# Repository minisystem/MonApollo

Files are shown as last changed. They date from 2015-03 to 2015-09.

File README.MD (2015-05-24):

=============================
Programmable Analog Monosynth
=============================
Prototype 
-------------
Digital Board
-------------

Digital board tested and working. SPI LED driving and switch reading tested. ADC pot reading but there is some cross-talk on
potentiometer ADC channels. Allowing sufficient settling time at ADC node between reads seems to mostly remedy this
to <= 1 LSB.

------------
Analog Board
------------
DAC S&H tested and working. There is some cross-talk (<= 10mV) on adjacent CV traces, but these are currently floating. Need to test
for crosstalk again once CV targets are installed.

NOISE/LFO/S&H tested and working, except for multiplexer latch problem mentioned below. Noise gain needed to be adjusted by
changing R180 to 10K and R181 to 750K (two 1.5M 0603s stacked in parallel). Also LFO module needede R3 (on module board) changed to 270K from 1M to get proper adjustment of sine/tri symmetry.
Sine symmetry is too 'pointy' on negative transition. Perhaps D1 and D2 need to be matched for Vf?

Bugs discovered thus far:

1. 7905 power regular pin error. Power supply rendered useless by this, so board requires external supply
2. LFO DG408 demultiplexer address lines are not latched, making LFO source addressing useless. Need to add 74LC75
latch in next revision.
2. C107 S&H sample cap footprint is 0805, but there are no NP0 or film caps in this footprint. Tried X7R and there was too much
droop. Through-hole film cap is in there now and droop is better, but still about 50-60 mV per second. This could be 
related to layout and leakage across PCB traces. A second look at layout shows definite room for improvement.
3. Glide circuit: Q6 PNP matched pair BCM857BS was flipped in schematic, swapping collectors and emitters. Good grief! Can't be salavaged
by a bodge, so will have to move on to VCO mod depth control and revisit glide in next PCB revision.
4. Glide slew caps C47 and C48 are currently 0603 but need to be 0805 or 1206 or even throughhole if film caps are to be used.

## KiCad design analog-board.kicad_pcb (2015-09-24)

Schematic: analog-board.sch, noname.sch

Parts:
C1, C8, C10, C18, C19, C20, C21, C22, C93, C94, C96, C97, C98, C99, C103, C104: 1µ
C2, C9, C11, C15, C17, C23, C24, C25, C26, C27, C28, C29, C30, C31, C32, C33, C34, C35, C36, C37, C38, C39, C40, C41, C42, C43, C44, C45, C46, C85, C88, C114, C115, C117, C118, C119, C120, C121, C122, C123, C124, C125, C126, C127, C128, C129, C130, C131, C132, C133: 0.1µ
C3, C4, C5, C12, C13, C14, C16, C81, C82, C83, C84, C86, C87, C101: 10p
C6, C7: 5.6p
C47, C48: 470n
C49, C50, C51, C52, C53, C54, C55, C56, C57, C58, C59, C60, C61, C62, C63, C64, C65, C66, C67, C68, C69, C70, C71, C72, C73, C74, C75, C76, C77, C78, C79, C80: 0.01µ
C89, C91: 47μ
C90, C107: 100n
C92: 10µ
C95: 10μ
C100, C134: 22µ
C102: 4.7n
C105, C106, C108, C109: 1000µ
C110: 1.5n
C111: 100pF
C112, C113, C116: 2.2µ
C135: 47p
D1, D2, D3, D4, D5, D6, D7, D8, D9, D10: DIODE
D11, D12: LED
D13: 1N4148
EG1, EG2: EG
J1: AC IN
J2: OUT
J3: CONN_20X2
LFO1: VCO
P2: CONN_01X02
Q1, Q2, Q3, Q4, Q5, Q7, Q8, Q9, Q10, Q11, Q12, Q13, Q14, Q15, Q16, Q20: 2N3906
Q6: BCM857BS
Q17, Q18: NPN
Q19: J111
R1, R2, R3, R4, R5, R26, R27, R28, R29, R30, R79, R80, R95, R96, R97, R104, R110, R111, R112, R113, R130, R131, R132, R133, R134, R151, R183, R198: 12K
R6, R7, R8, R9, R13, R16, R17, R19, R20, R21, R87, R88, R89, R90, R98, R101, R114, R115, R118, R119, R122, R123, R124, R125, R135, R140, R188, R190: 510
R10, R11, R12, R24, R25, R91, R92, R102, R116, R117, R120, R121, R145, R174, R192: 2.2M
R14, R15, R18, R126, R127, R128, R129: 68K
R22, R23, R93, R94, R103, R146, R170, R171, R196: 18K
R31, R32, R33, R34, R38, R99, R100, R105, R136, R137, R138, R139, R152, R200: 47K
R35, R36, R37, R141, R142, R143, R144: 91K
R39, R189, R193, R206, R207: 1K
R40, R41, R42, R147, R148, R149, R150: 270K
R43, R44, R45, R46, R47, R48, R49, R50, R51, R52, R53, R54, R55, R56, R57, R58, R59, R60, R61, R62, R63, R64, R65, R66, R67, R70, R71, R72, R73, R74, R75, R77, R78, R81, R84, R153, R154, R155, R156, R157, R158, R159, R163, R164, R165, R167, R173, R175, R176, R184, R199, R202, R204: 100K
R68: 33K
R69: 1K 3300ppm/K
R76: 39K
R82, R83, R85, R86: 4.7K
R106, R107, R108, R109: 100K
R160, R205: 10K
R161: 3.3M
R162: 390K
R166, R168: 27K
R169: 680K**
R172: 47K
R177: 150K
R178: 22
R179, R185, R191, R201, R211, R213, R215: 10K
R180: 15K
R181, R203: 470K
R182: 120K
R186: 1.5K
R187, R195: 18K
R194: 20K
R197: 2.2meg
R208, R209: 220K
R210: 3.3K
R212, R214: 9.1K
R216: 270K
R217: 22K
TP1, TP2, TP3, TP4, TP5, TP6, TP7, TP8, TP9, TP10, TP11, TP12, TP13, TP14, TP15, TP16, TP17, TP18, TP19, TP20, TP21, TP22, TP23, TP24, TP25, TP26, TP27, TP28, TP29, TP30, TP31, TP32, TP33, TP34, TP35, TP36, TP37, TP38, TP39: CONN_1
TR1, TR2, TR3, TR4, TR5, TR8, TR9, TR10, TR11, TR12, TR13, TR14, TR15, TR16, TR18, TR19, TR21, TR23: 100K
TR6, TR7, TR17, TR20, TR22: 20K
U1, U2, U3, U18, U19, U29, U30, U32: LM13700
U4, U12: DG212B
U5, U8, U22, U23, U24, U25, U27, U28, U31, U33, U34, U35, U39: TL074-
U6: AD5556
U7, U15, U21, U26: TL072-
U9: AD8672
U10: ADR01
U11: DG212B; TSSOP-16
U13, U14, U16, U17, U45: DG408
U20: 74HC75
U36: 74LV573; Digikey SN74LV573APWR
U38, U41: 0 - 10V
U40: DG419
U42: 10 - 0V
U43: LM7812
U44: LM7912
U46: 7805
VCFA1: VCF_VCA
VCO1, VCO2: VCO

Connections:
+5V: C1.1 (+), C2.1, C88.1, C116.1 (+), TP35.1, U4.12 (VL), U6.28 (VDD), U11.12 (VL), U12.12 (VL), U20.5 (VCC), U36.20 (VCC), U40.5 (VCC), U46.3 (VO)
+12V: C8.1 (+), C9.1, C17.1, C18.1 (+), C21.1, C22.1, C25.1, C26.1, C27.1, C29.1, C31.1, C33.1, C35.1, C39.1, C40.1, C41.1, C43.1, C45.1, C85.1, C94.1, C97.1, C98.1, C104.1, C112.1 (+), C115.1, C118.1, C120.1, C122.1, C124.1, C126.1, C128.1, C130.1, C132.1, D9.2 (K), EG1.1 (V+), EG2.1 (V+), J3.1, J3.2, LFO1.2 (V+), R26.2, R27.2, R28.2, R29.2, R30.2, R76.2, R95.2, R96.2, R104.2, R130.2, R131.2, R133.2, R134.2, R151.2, R178.1, R184.1, R198.2, R206.1, R216.2, TP33.1, TR1.3, TR2.3, TR3.3, TR4.3, TR5.3, TR8.3, TR9.3, TR10.3, TR11.3, TR12.3, TR13.3, TR14.3, TR15.3, TR16.3, TR18.1, TR21.1, TR23.3, U1.11 (V+), U2.11 (V+), U3.11 (V+), U4.13 (V+), U5.4 (V+), U7.8 (V+), U8.4 (V+), U9.8 (V+), U10.3 (VIN), U11.13 (V+), U12.13 (V+), U13.13 (V+), U14.13 (V+), U15.8 (V+), U16.13 (V+), U17.13 (V+), U18.11 (V+), U19.11 (V+), U21.8 (V+), U22.4 (V+), U23.4 (V+), U24.4 (V+), U25.4 (V+), U26.8 (V+), U27.4 (V+), U28.4 (V+), U29.11 (V+), U30.11 (V+), U31.4 (V+), U32.11 (V+), U33.4 (V+), U34.4 (V+), U35.4 (V+), U39.4 (V+), U40.4 (V+), U43.3 (VO), U45.2 (EN), U45.13 (V+), U46.1 (VI), VCFA1.4 (V+), VCO1.2 (V+), VCO2.2 (V+)
-12V: C10.2 (-), C11.2, C19.1, C20.1, C23.1, C24.1, C28.2, C30.2, C32.2, C34.2, C36.2, C37.1, C38.1, C42.2, C44.2, C46.2, C93.1, C96.1, C99.1, C103.1, C113.2 (-), C114.1, C117.2, C119.2, C121.2, C123.2, C125.2, C127.2, C129.2, C131.2, C133.2, D10.1 (A), EG1.3 (V-), EG2.3 (V-), LFO1.3 (V-), R162.2, R207.2, R208.1, R209.1, TP34.1, TR1.1, TR2.1, TR3.1, TR4.1, TR5.1, TR8.1, TR9.1, TR10.1, TR11.1, TR12.1, TR13.1, TR14.1, TR15.1, TR16.1, TR18.3, TR19.1, TR21.3, TR23.1, U1.6 (V-), U2.6 (V-), U3.6 (V-), U4.4 (V-), U5.11 (V-), U7.4 (V-), U8.11 (V-), U9.4 (V-), U11.4 (V-), U12.4 (V-), U13.3 (V-), U14.3 (V-), U15.4 (V-), U16.3 (V-), U17.3 (V-), U18.6 (V-), U19.6 (V-), U21.4 (V-), U22.11 (V-), U23.11 (V-), U24.11 (V-), U25.11 (V-), U26.4 (V-), U27.11 (V-), U28.11 (V-), U29.6 (V-), U30.6 (V-), U31.11 (V-), U32.6 (V-), U33.11 (V-), U34.11 (V-), U35.11 (V-), U39.11 (V-), U44.3 (VO), U45.3 (V-), VCFA1.5 (V-), VCO1.3 (V-), VCO2.3 (V-)
/DAC0: J3.35, U6.6 (DB0)
/DAC1: J3.34, U6.5 (DB1)
/DAC2: J3.33, U6.4 (DB2)
/DAC3: J3.32, U6.3 (DB3)
/DAC4: J3.31, U6.2 (DB4)
/DAC5: J3.30, U6.1 (DB5)
/DAC6: J3.29, U6.27 (DB6)
/DAC7: J3.28, U6.26 (DB7)
/DAC8: J3.25, U6.25 (DB8)
/DAC9: J3.24, U6.24 (DB9)
/DAC10: J3.23, U6.23 (DB10)
/DAC11: J3.22, U6.22 (DB11)
/DAC12: J3.21, U6.21 (DB12)
/DAC13: J3.20, U6.20 (DB13)
/VREF: C15.1, TP9.1, U6.11 (R1), U10.4 (VOUT)
AMP LFO AMT CV: R146.1, U28.8, U28.9 (-)
ANALOG SW LATCH: J3.36, U36.11 (Load)
CUTOFF CV: R158.2, U28.1, U28.2 (-)
DAC MUX EN0: J3.19, U13.2 (EN)
DAC MUX EN1: J3.18, U14.2 (EN)
DAC MUX EN2: J3.17, U16.2 (EN)
DAC MUX EN3: J3.16, U17.2 (EN)
DB0: J3.8, U13.1 (A0), U14.1 (A0), U16.1 (A0), U17.1 (A0), U20.2 (D0), U36.2 (D0)
DB1: J3.9, U13.16 (A1), U14.16 (A1), U16.16 (A1), U17.16 (A1), U20.3 (D1), U36.3 (D1)
DB2: J3.10, U13.15 (A2), U14.15 (A2), U16.15 (A2), U17.15 (A2), U20.6 (D2), U36.4 (D2)
DB3: J3.11, U36.5 (D3)
DB4: J3.12, U36.6 (D4)
DB5: J3.13, U36.7 (D5)
DB6: J3.14, U36.8 (D6)
DB7: J3.15, U36.9 (D7)
EG1: EG1.6 (OUT), R154.2
EG1 ATT CV: EG1.10 (A), U33.1, U33.2 (-)
EG1 DEC CV: EG1.9 (D), U33.6 (-), U33.7
EG1 REL CV: EG1.8 (R), U33.13 (-), U33.14
EG1 SUS CV: EG1.7 (S), U33.8, U33.9 (-)
EG2: R3.1, R5.1, R111.1, U40.1 (COM)
EG2 ATT CV: EG2.10 (A), U34.1, U34.2 (-)
EG2 DEC CV: EG2.9 (D), U34.6 (-), U34.7
EG2 POL: J3.38, U40.6 (A/B)
EG2 REL CV: EG2.8 (R), U34.13 (-), U34.14
EG2 SUS CV: EG2.7 (S), U34.8, U34.9 (-)
EXT_CV_IN: R173.2, R199.2, TP38.1
FIL EG2 AMT CV: R127.1, U27.13 (-), U27.14
FIL LFO AMT CV: R128.1, U27.6 (-), U27.7
FIL OSCB AMT CV: R129.1, U27.1, U27.2 (-)
GATE: EG1.2 (GATE), EG2.2 (GATE), J3.3, TP39.1
GLIDE AMT CV: R68.2, U24.6 (-), U24.7
GND: C1.2 (-), C2.2, C8.2 (-), C9.2, C10.1 (+), C11.1, C15.2, C17.2, C18.2 (-), C19.2, C20.2, C21.2, C22.2, C23.2, C24.2, C25.2, C26.2, C27.2, C28.1, C29.2, C30.1, C31.2, C32.1, C33.2, C34.1, C35.2, C36.1, C37.2, C38.2, C39.2, C40.2, C41.2, C42.1, C43.2, C44.1, C45.2, C46.1, C47.2, C48.2, C49.2, C50.2, C51.2, C52.2, C53.2, C54.2, C55.2, C56.2, C57.2, C58.2, C59.2, C60.2, C61.2, C62.2, C63.2, C64.2, C65.2, C66.2, C67.2, C68.2, C69.2, C70.2, C71.2, C72.2, C73.2, C74.2, C75.2, C76.2, C77.2, C78.2, C79.2, C80.2, C85.2, C88.2, C89.2 (-), C90.2, C93.2, C94.2, C96.2, C97.2, C98.2, C99.2, C103.2, C104.2, C105.2 (-), C106.1 (+), C107.2, C108.2 (-), C109.1 (+), C112.2 (-), C113.1 (+), C114.2, C115.2, C116.2 (-), C117.1, C118.2, C119.1, C120.2, C121.1, C122.2, C123.1, C124.2, C125.1, C126.2, C127.1, C128.2, C129.1, C130.2, C131.1, C132.2, C133.1, D1.2 (K), D2.1 (A), D3.1 (A), D6.2 (K), D8.2 (K), D9.1 (A), D10.2 (K), D11.2 (K), D12.1 (A), EG1.4 (GND), EG2.4 (GND), J2.1, J3.39, J3.40, LFO1.1 (GND), LFO1.6 (GND), LFO1.10 (PWM), LFO1.12 (GND), Q1.2 (B), Q2.2 (B), Q3.2 (B), Q4.2 (B), Q5.2 (B), Q6.2 (B1), Q6.6 (C1), Q7.2 (B), Q8.2 (B), Q9.2 (B), Q10.2 (B), Q11.2 (B), Q12.2 (B), Q13.2 (B), Q14.2 (B), Q15.2 (B), Q16.2 (B), Q17.2 (B), Q17.3 (C), Q18.1 (E), Q20.2 (B), R6.1, R7.1, R8.1, R9.1, R13.1, R16.1, R17.1, R19.1, R20.1, R21.1, R31.1, R32.1, R33.1, R34.1, R38.1, R69.2, R87.1, R88.1, R89.1, R90.1, R98.1, R99.1, R100.1, R101.1, R105.1, R114.1, R115.1, R118.1, R119.1, R122.1, R123.1, R124.1, R125.1, R135.1, R136.1, R137.1, R138.1, R139.1, R140.1, R152.1, R160.1, R185.2, R186.2, R187.2, R188.1, R190.1, R193.2, R194.2, R200.1, R201.2, R205.2, R212.1, R214.1, R217.1, TP31.1, TP32.1, TP36.1, TP37.1, TR19.3, U4.5 (GND), U5.3 (+), U5.5 (+), U5.10 (+), U5.12 (+), U6.17 (MSB), U6.19 (GND), U7.3 (+), U7.5 (+), U8.3 (+), U8.5 (+), U8.10 (+), U8.12 (+), U9.3 (+), U9.5 (+), U10.2 (GND), U11.5 (GND), U12.5 (GND), U13.14 (GND), U14.14 (GND), U15.3 (+), U15.5 (+), U16.14 (GND), U17.14 (GND), U20.7 (D3), U20.12 (GND), U26.3 (+), U31.3 (+), U31.5 (+), U31.10 (+), U31.12 (+), U35.3 (+), U35.5 (+), U35.12 (+), U36.1 (OE), U36.10 (GND), U39.12 (+), U40.3 (GND), U40.7 (V-), U43.2 (GND), U44.1 (GND), U45.9 (S7), U45.10 (S6), U45.11 (S5), U45.14 (GND), U46.2 (GND), VCFA1.8 (GND), VCFA1.9 (GND), VCO1.1 (GND), VCO1.6 (GND), VCO1.12 (GND), VCO2.1 (GND), VCO2.6 (GND), VCO2.12 (GND)
KEYTRACK AMT CV: R126.1, U27.8, U27.9 (-)
LFO: J3.5, R1.1, R4.1, R112.1, R132.1, TP28.1, U45.8 (D)
LFO DMUX EN: J3.37, U20.4 (E23), U20.13 (E01)
LFO RATE CV: R176.2, U22.8, U22.9 (-)
LFO RESET: J3.7, LFO1.11 (SYNC)
LFO TUNE: J3.6, R215.1
NOISE: C101.2, R97.1, R181.1, R191.2, TP12.1, U39.14
NOISE MIX CV: R103.1, U23.6 (-), U23.7
unnamed: C3.1, R35.1, R40.2, U5.13 (-)
unnamed: C3.2, R40.1, R67.1, TP3.1, U5.14
unnamed: C4.1, R36.1, R41.2, U5.2 (-)
unnamed: C5.1, R37.1, R42.2, U5.9 (-)
unnamed: C6.1, U6.13 (REF), U9.1
unnamed: C6.2, U6.12 (RCOM), U9.2 (-)
unnamed: C7.2, U6.14 (IOUT), U9.6 (-)
unnamed: C12.1, R49.1, R53.2, U8.2 (-)
unnamed: C12.2, R53.1, R57.2, U8.1
unnamed: C13.1, R51.1, R54.1, U5.6 (-)
unnamed: C13.2, R54.2, R64.1, U5.7
unnamed: C14.1, R55.1, R61.2, U7.2 (-)
unnamed: C14.2, R61.1, U7.1, VCO1.10 (PWM)
unnamed: C16.1, R56.1, R62.2, U8.9 (-)
unnamed: C16.2, R62.1, U8.8, VCO2.10 (PWM)
unnamed: C47.1, U18.12, U21.3 (+)
unnamed: C48.1, U18.5, U21.5 (+)
unnamed: C81.1, R141.1, R147.2, U31.2 (-)
unnamed: C81.2, R147.1, R156.2, TP18.1, U31.1
unnamed: C82.1, R142.1, R148.2, U31.13 (-)
unnamed: C82.2, R148.1, R155.2, TP19.1, U31.14
unnamed: C83.1, R143.1, R149.2, U31.9 (-)
unnamed: C83.2, R149.1, R157.2, TP20.1, U31.8
unnamed: C84.1, R144.1, R150.2, U31.6 (-)
unnamed: C84.2, R150.1, R159.2, TP21.1, U31.7
unnamed: C86.1, R155.1, R156.1, R157.1, R158.1, R159.1, R162.1, R164.2, U35.6 (-)
unnamed: C86.2, R164.1, TP22.1, TR20.2, TR20.3, U35.7
unnamed: C87.1, R165.1, R167.2, U35.2 (-)
unnamed: C87.2, R167.1, R168.2, U35.1
unnamed: C89.1 (+), R172.1, R178.2, R179.1
unnamed: C90.1, R170.1, R171.2
unnamed: C91.1 (+), Q17.1 (E), R172.2
unnamed: C91.2 (-), Q18.2 (B), R177.2
unnamed: C92.1 (+), VCFA1.1 (IN)
unnamed: C92.2 (-), R109.2, TP30.1, U26.1
unnamed: C95.1 (+), Q18.3 (C), R177.1, R179.2, TP23.1
unnamed: C95.2 (-), R180.2
unnamed: C100.1 (+), C135.1, TP24.1, U26.5 (+), VCFA1.10 (OUT)
unnamed: C100.2 (-), R183.1
unnamed: C101.1, R180.1, R181.2, U39.13 (-)
unnamed: C102.1, LFO1.9, R210.2
unnamed: C102.2, R189.1
unnamed: C105.1 (+), C108.1 (+), D7.2 (K), D8.1 (A), P2.2, U43.1 (VI)
unnamed: C106.2 (-), C109.2 (-), D5.1 (A), D7.1 (A), U44.2 (VI)
unnamed: C107.1, Q19.1 (S), U39.5 (+)
unnamed: C110.1, R201.1, R203.2, U39.6 (-)
unnamed: C110.2, R203.1, TP27.1, U39.7, U45.12 (S4)
unnamed: C111.1, R202.2, R204.1, U35.13 (-)
unnamed: C111.2, R39.1, R204.2, U35.14
unnamed: C134.1 (+), R200.2, U32.5
unnamed: C134.2 (-), R202.1, TP26.1
unnamed: C135.2, D13.1 (A), U26.7
unnamed: D1.1 (A), D2.2 (K), R182.1, R187.1, U39.3 (+)
unnamed: D3.2 (K), R189.2, R194.1, U39.10 (+)
unnamed: D4.1 (A), Q19.3 (G), R197.2
unnamed: D4.2 (K), R215.2, TP25.1, U39.8
unnamed: D5.2 (K), D6.1 (A), J1.3
unnamed: D11.1 (A), R206.2
unnamed: D12.2 (K), R207.1
unnamed: EG2.5 (INV), U40.8 (A)
unnamed: EG2.6 (OUT), U40.2 (B)
unnamed: J1.1, P2.1
unnamed: J2.3, R39.2
unnamed: LFO1.4 (PITCH), R175.1, R176.1, TR22.1, TR22.2
unnamed: LFO1.5 (SCALE), LFO1.~ (SCALE), TR22.3
unnamed: LFO1.7, R182.2, U45.4 (S0)
unnamed: LFO1.8, U45.6 (S2)
unnamed: Q1.1 (E), R14.2
unnamed: Q1.3 (C), U1.16
unnamed: Q2.1 (E), R15.2
unnamed: Q2.3 (C), U1.1
unnamed: Q3.1 (E), R18.2
unnamed: Q3.3 (C), U2.16
unnamed: Q4.1 (E), R23.2
unnamed: Q4.3 (C), U3.1
unnamed: Q5.1 (E), R22.2
unnamed: Q5.3 (C), U3.16
unnamed: Q6.1 (E1), Q6.4 (E2), R76.1
unnamed: Q6.3 (C2), R81.2, R84.2
unnamed: Q6.5 (B2), R68.1, R69.1
unnamed: Q7.1 (E), R93.2
unnamed: Q7.3 (C), U19.16
unnamed: Q8.1 (E), R94.2
unnamed: Q8.3 (C), U19.1
unnamed: Q9.1 (E), R103.2
unnamed: Q9.3 (C), U2.1
unnamed: Q10.1 (E), R126.2
unnamed: Q10.3 (C), U29.16
unnamed: Q11.1 (E), R127.2
unnamed: Q11.3 (C), U29.1
unnamed: Q12.1 (E), R128.2
unnamed: Q12.3 (C), U30.16
unnamed: Q13.1 (E), R129.2
unnamed: Q13.3 (C), U30.1
unnamed: Q14.1 (E), R146.2
unnamed: Q14.3 (C), U32.16
unnamed: Q15.1 (E), R166.1
unnamed: Q15.3 (C), VCFA1.3 (RES)
unnamed: Q16.1 (E), R168.1
unnamed: Q16.3 (C), VCFA1.2 (AMP)
unnamed: Q19.2 (D), R191.1, R193.1, R197.1
unnamed: Q20.1 (E), R196.2
unnamed: Q20.3 (C), U32.1
unnamed: R1.2, R9.2, U3.3 (+)
unnamed: R6.2, R10.1, U1.14 (+)
unnamed: R10.2, TR1.2
unnamed: R7.2, R11.1, U1.3 (+)
unnamed: R11.2, TR2.2
unnamed: R8.2, R12.1, U2.14 (+)
unnamed: R12.2, TR3.2
unnamed: R5.2, R13.2, U3.14 (+)
unnamed: R2.2, R16.2, U1.13 (-)
unnamed: R3.2, R17.2, U1.4 (-)
unnamed: R4.2, R19.2, U2.13 (-)
unnamed: R20.2, R24.2, U3.4 (-)
unnamed: R21.2, R25.2, U3.13 (-)
unnamed: R24.1, TR4.2
unnamed: R25.1, TR5.2
unnamed: R26.1, U1.15
unnamed: R27.1, U1.2
unnamed: R28.1, U2.15
unnamed: R29.1, U3.2
unnamed: R30.1, U3.15
unnamed: R31.2, R35.2, U1.12
unnamed: R32.2, R36.2, U1.5
unnamed: R33.2, R37.2, U2.12
unnamed: R47.2, U4.7
unnamed: R48.2, U4.10
unnamed: R50.1, R55.2, TP6.1, U7.7
unnamed: R52.1, R56.2, TP7.1, U8.7
unnamed: R58.2, U4.2
unnamed: R60.2, U4.15
unnamed: R70.1, R71.1, R72.1, R77.2, U15.2 (-)
unnamed: R70.2, U11.10
unnamed: R71.2, U11.15
unnamed: R72.2, U11.2
unnamed: R73.1, R74.1, R75.1, R78.2, U15.6 (-)
unnamed: R73.2, U12.15
unnamed: R74.2, U12.2
unnamed: R75.2, U12.7
unnamed: R77.1, R79.1, TP10.1, U15.1
unnamed: R78.1, R80.1, TP11.1, U15.7
unnamed: R79.2, R87.2, U19.14 (+)
unnamed: R80.2, R88.2, U19.3 (+)
unnamed: R81.1, U18.16
unnamed: R82.2, U18.14 (+)
unnamed: R83.2, U18.13 (-)
unnamed: R84.1, U18.1
unnamed: R85.2, U18.3 (+)
unnamed: R86.2, U18.4 (-)
unnamed: R89.2, R91.2, U19.13 (-)
unnamed: R90.2, R92.2, U19.4 (-)
unnamed: R91.1, TR8.2
unnamed: R92.1, TR9.2
unnamed: R95.1, U19.15
unnamed: R96.1, U19.2
unnamed: R97.2, R98.2, U2.3 (+)
unnamed: R100.2, R108.1, TP16.1, U19.5
unnamed: R101.2, R102.2, U2.4 (-)
unnamed: R102.1, TR10.2
unnamed: R104.1, U2.2
unnamed: R105.2, R107.1, TP15.1, U2.5
unnamed: R99.2, R106.1, TP17.1, U19.12
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

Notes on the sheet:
DG212 POWER CONNECTIONS
LFO SPEED INIT
Adjust R(Iabc) for unity gain
CV MIX OFFSET NULL
SELECTED
NP0 or FILM
LFO CLOCK
S&H OUT
S&H
PULSE
SAW
SINE
TRI
LFO + NOISE + S&H
SCALE TRIM
GLIDE
VCF CTRL offset
(+4V to -6V)
**may need to lower to 510K or 560K for 12V PWR
VCF CTRL input modified from Juno 106 VCF input for 0-10V response
ENVELOPE GENERATORS
ANALOG SWITCH LATCH
DAC BUS
S&H DECOUPLING
VDAC MULTIPLEXING
CV SAMPLE & HOLDS
DAC and DAC 10V reference
12V AC from wall adapter
POWER SUPPLY
NOISE + S&H from YUSYNTH LFO module is VCO SIP with 100nF integrator cap and 1nF FET reset cap
ADAPTED FROM SCI PROPHET 5 GLIDE CIRCUIT
*** PULSE FALLING EDGE THEN RISING EDGE SEE AD5556 DATASHEET
***
single turn
SPARE
A GND
D GND
SWITCH JUMPER
OP AMP and SWITCH DECOUPLING
EXT CV IN

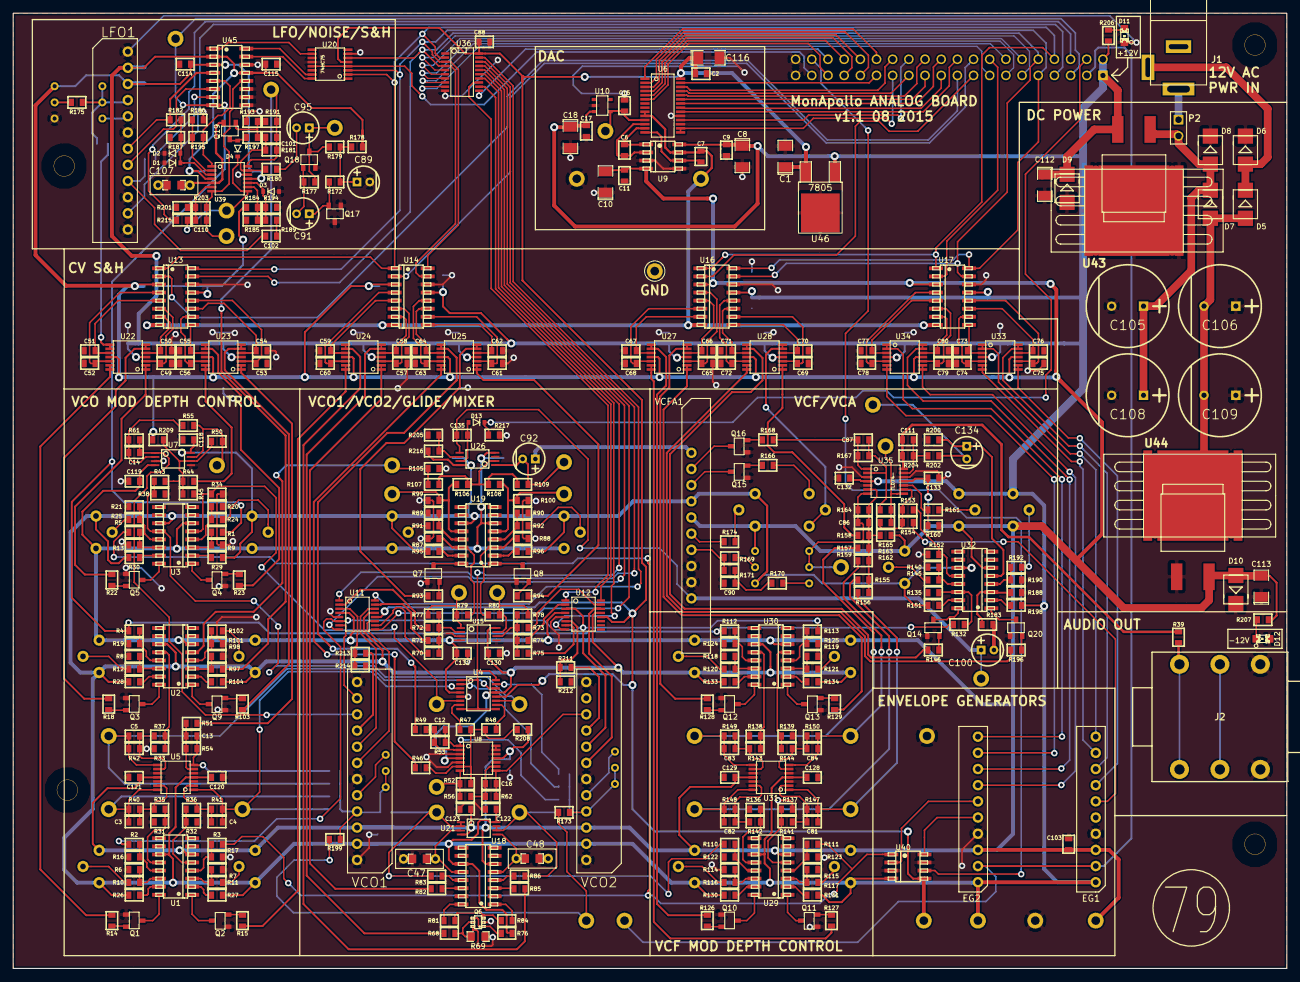
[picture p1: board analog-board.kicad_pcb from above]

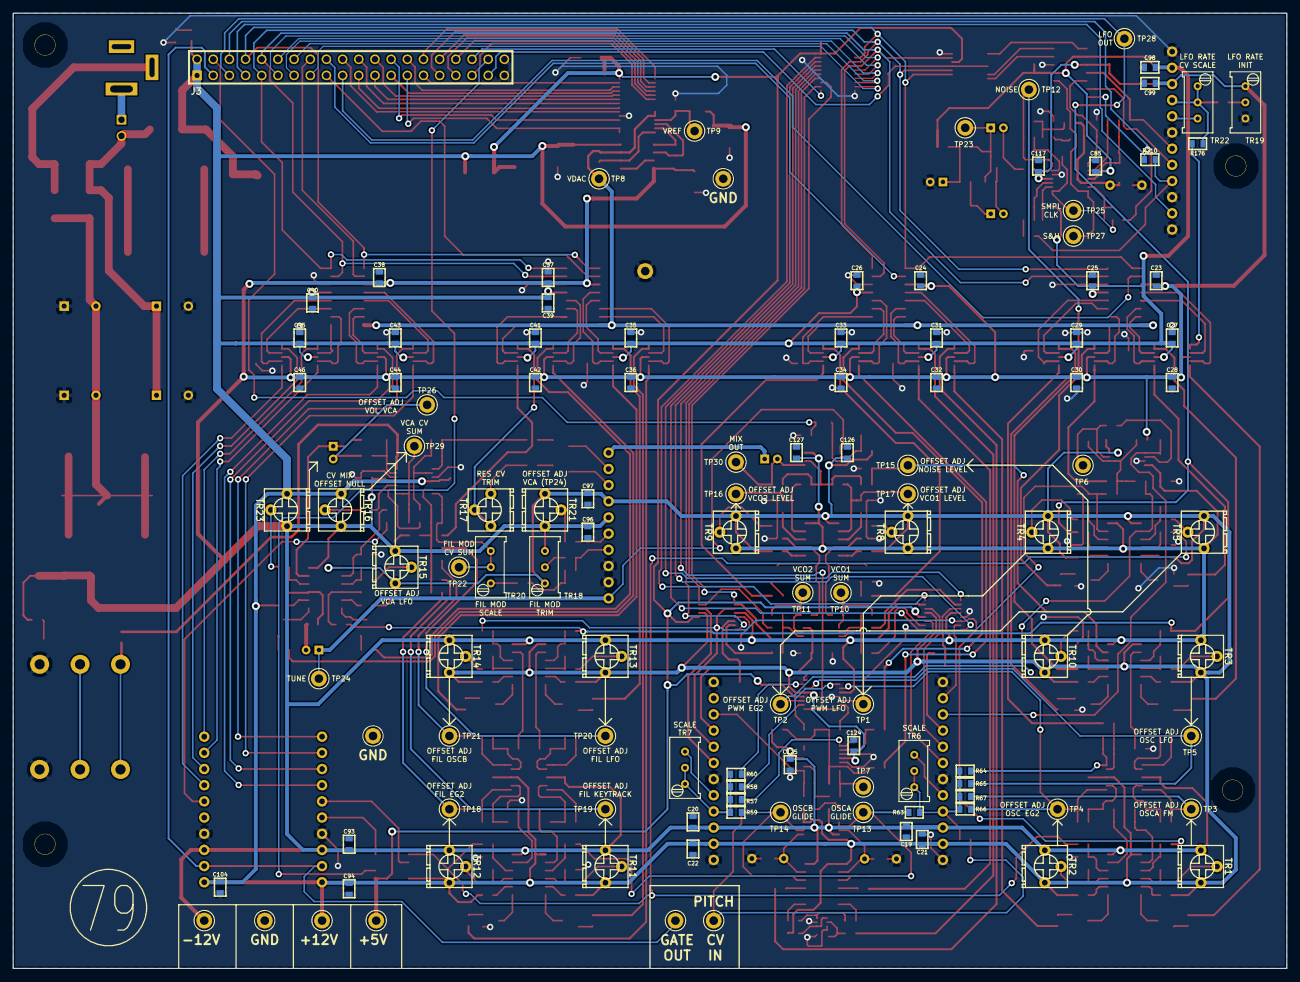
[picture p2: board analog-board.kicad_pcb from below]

Board: 2 copper layers, 200.0 x 150.0 mm, 506 parts (115 on the bottom side), 352 nets.

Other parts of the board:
HOLE-0.125-INCH, HOLE-0.125-INCH#2, HOLE-0.125-INCH#3, HOLE-0.125-INCH#4: VAL**; HOLE-0.125-INCH

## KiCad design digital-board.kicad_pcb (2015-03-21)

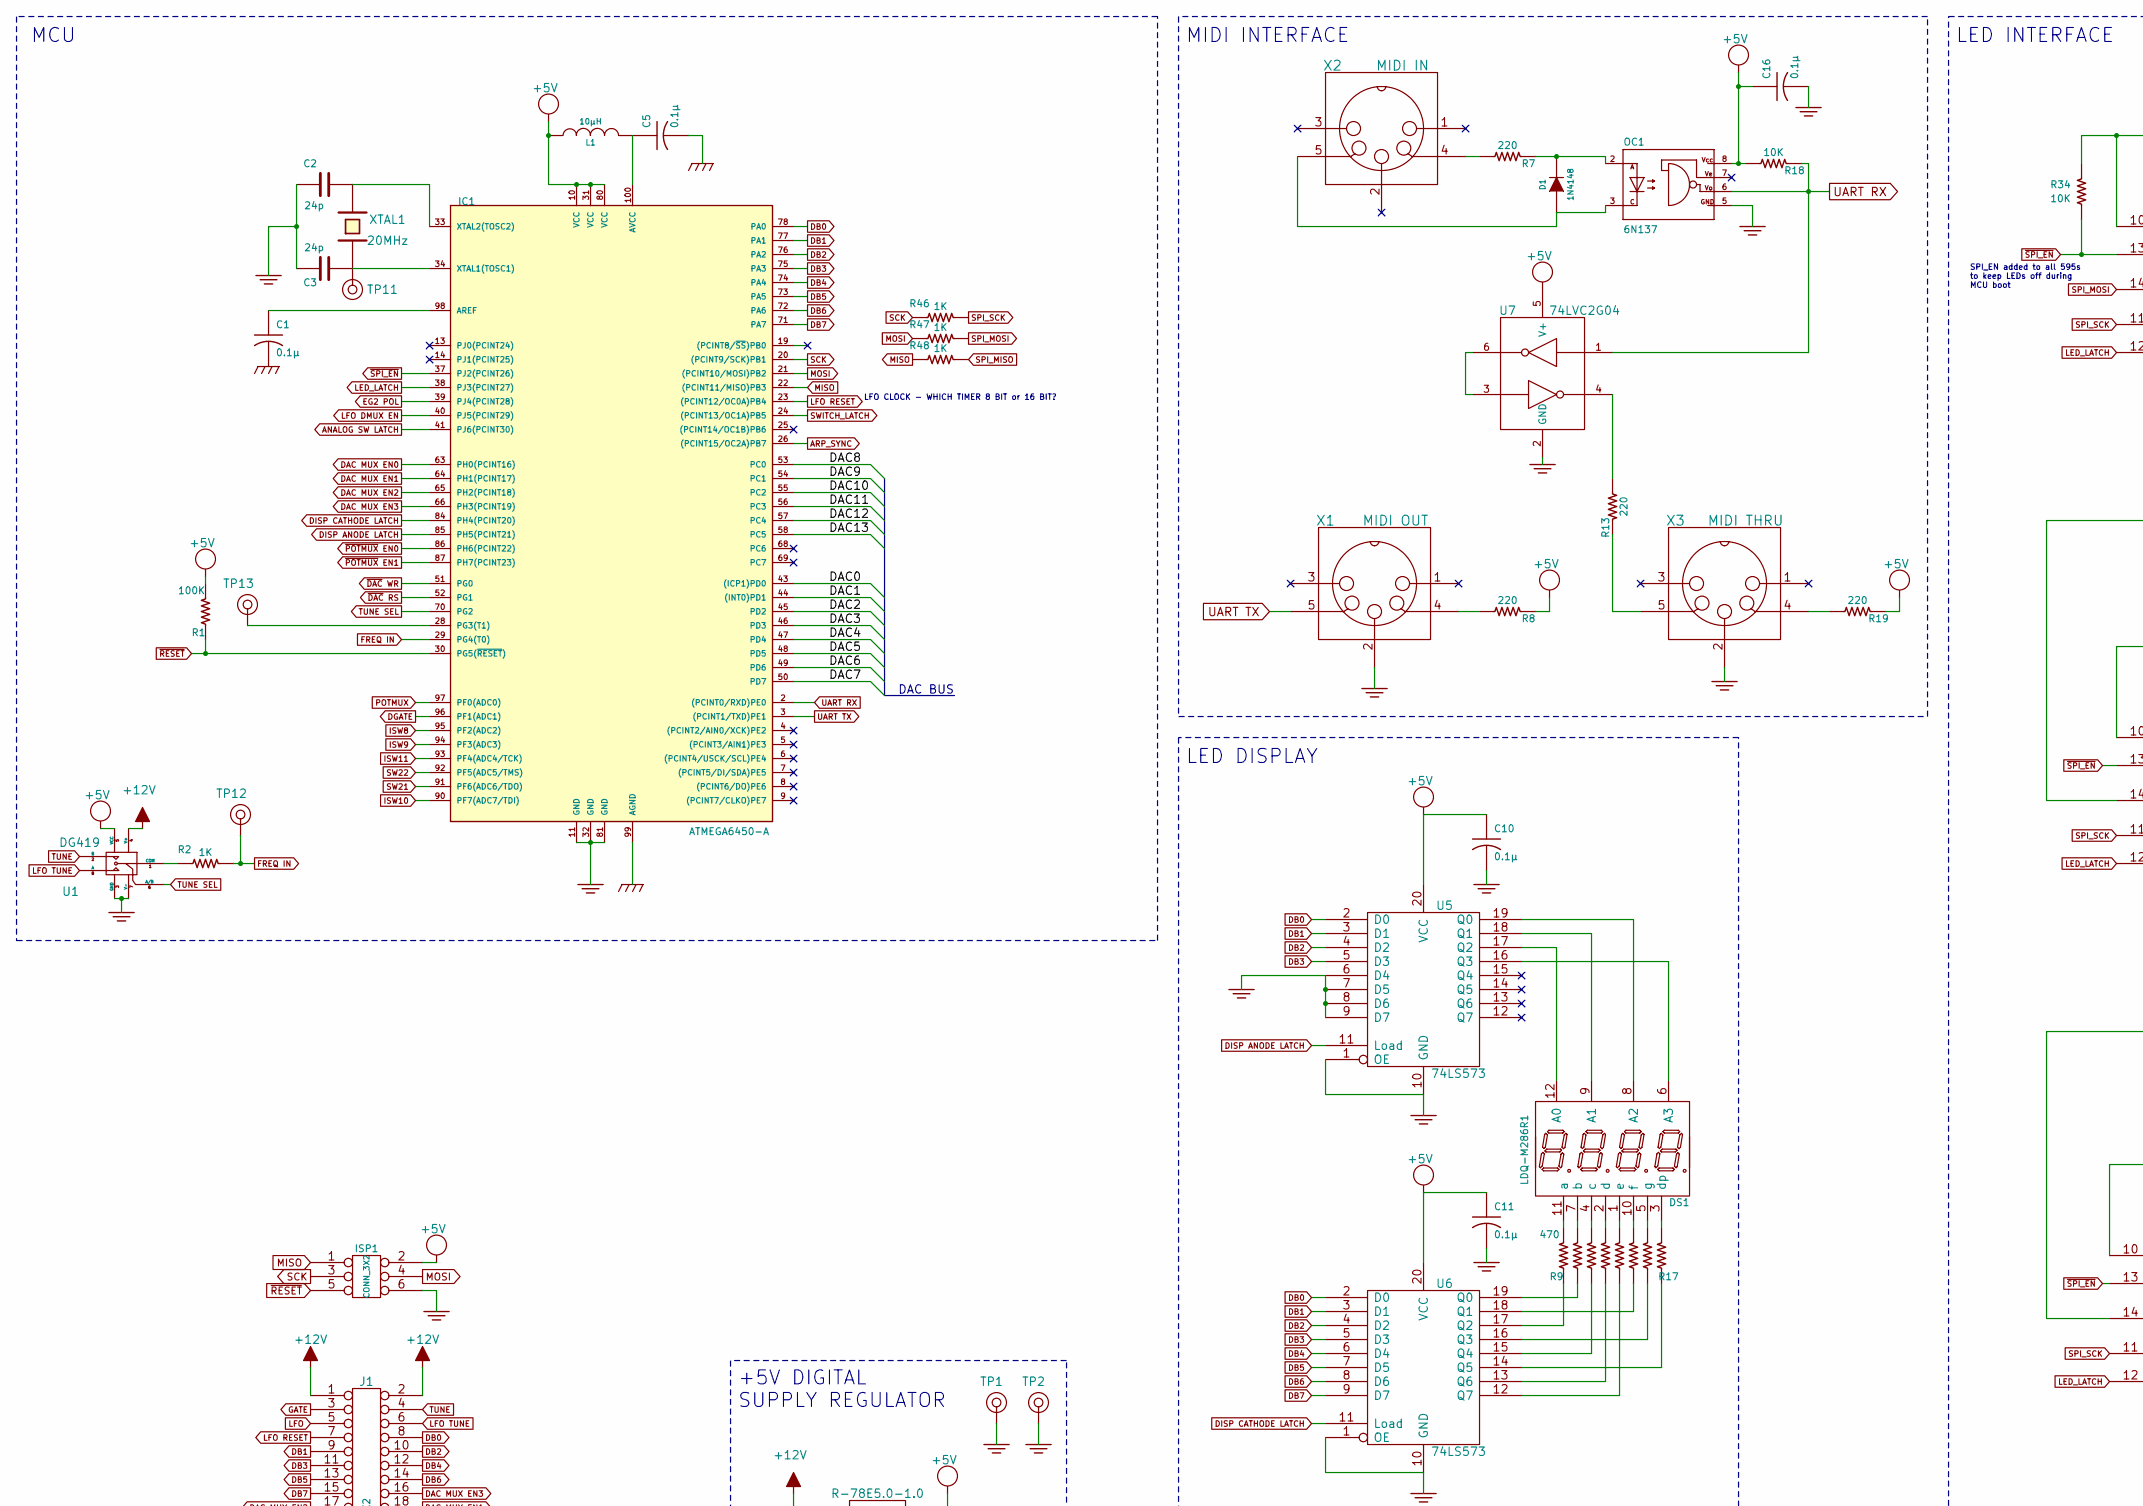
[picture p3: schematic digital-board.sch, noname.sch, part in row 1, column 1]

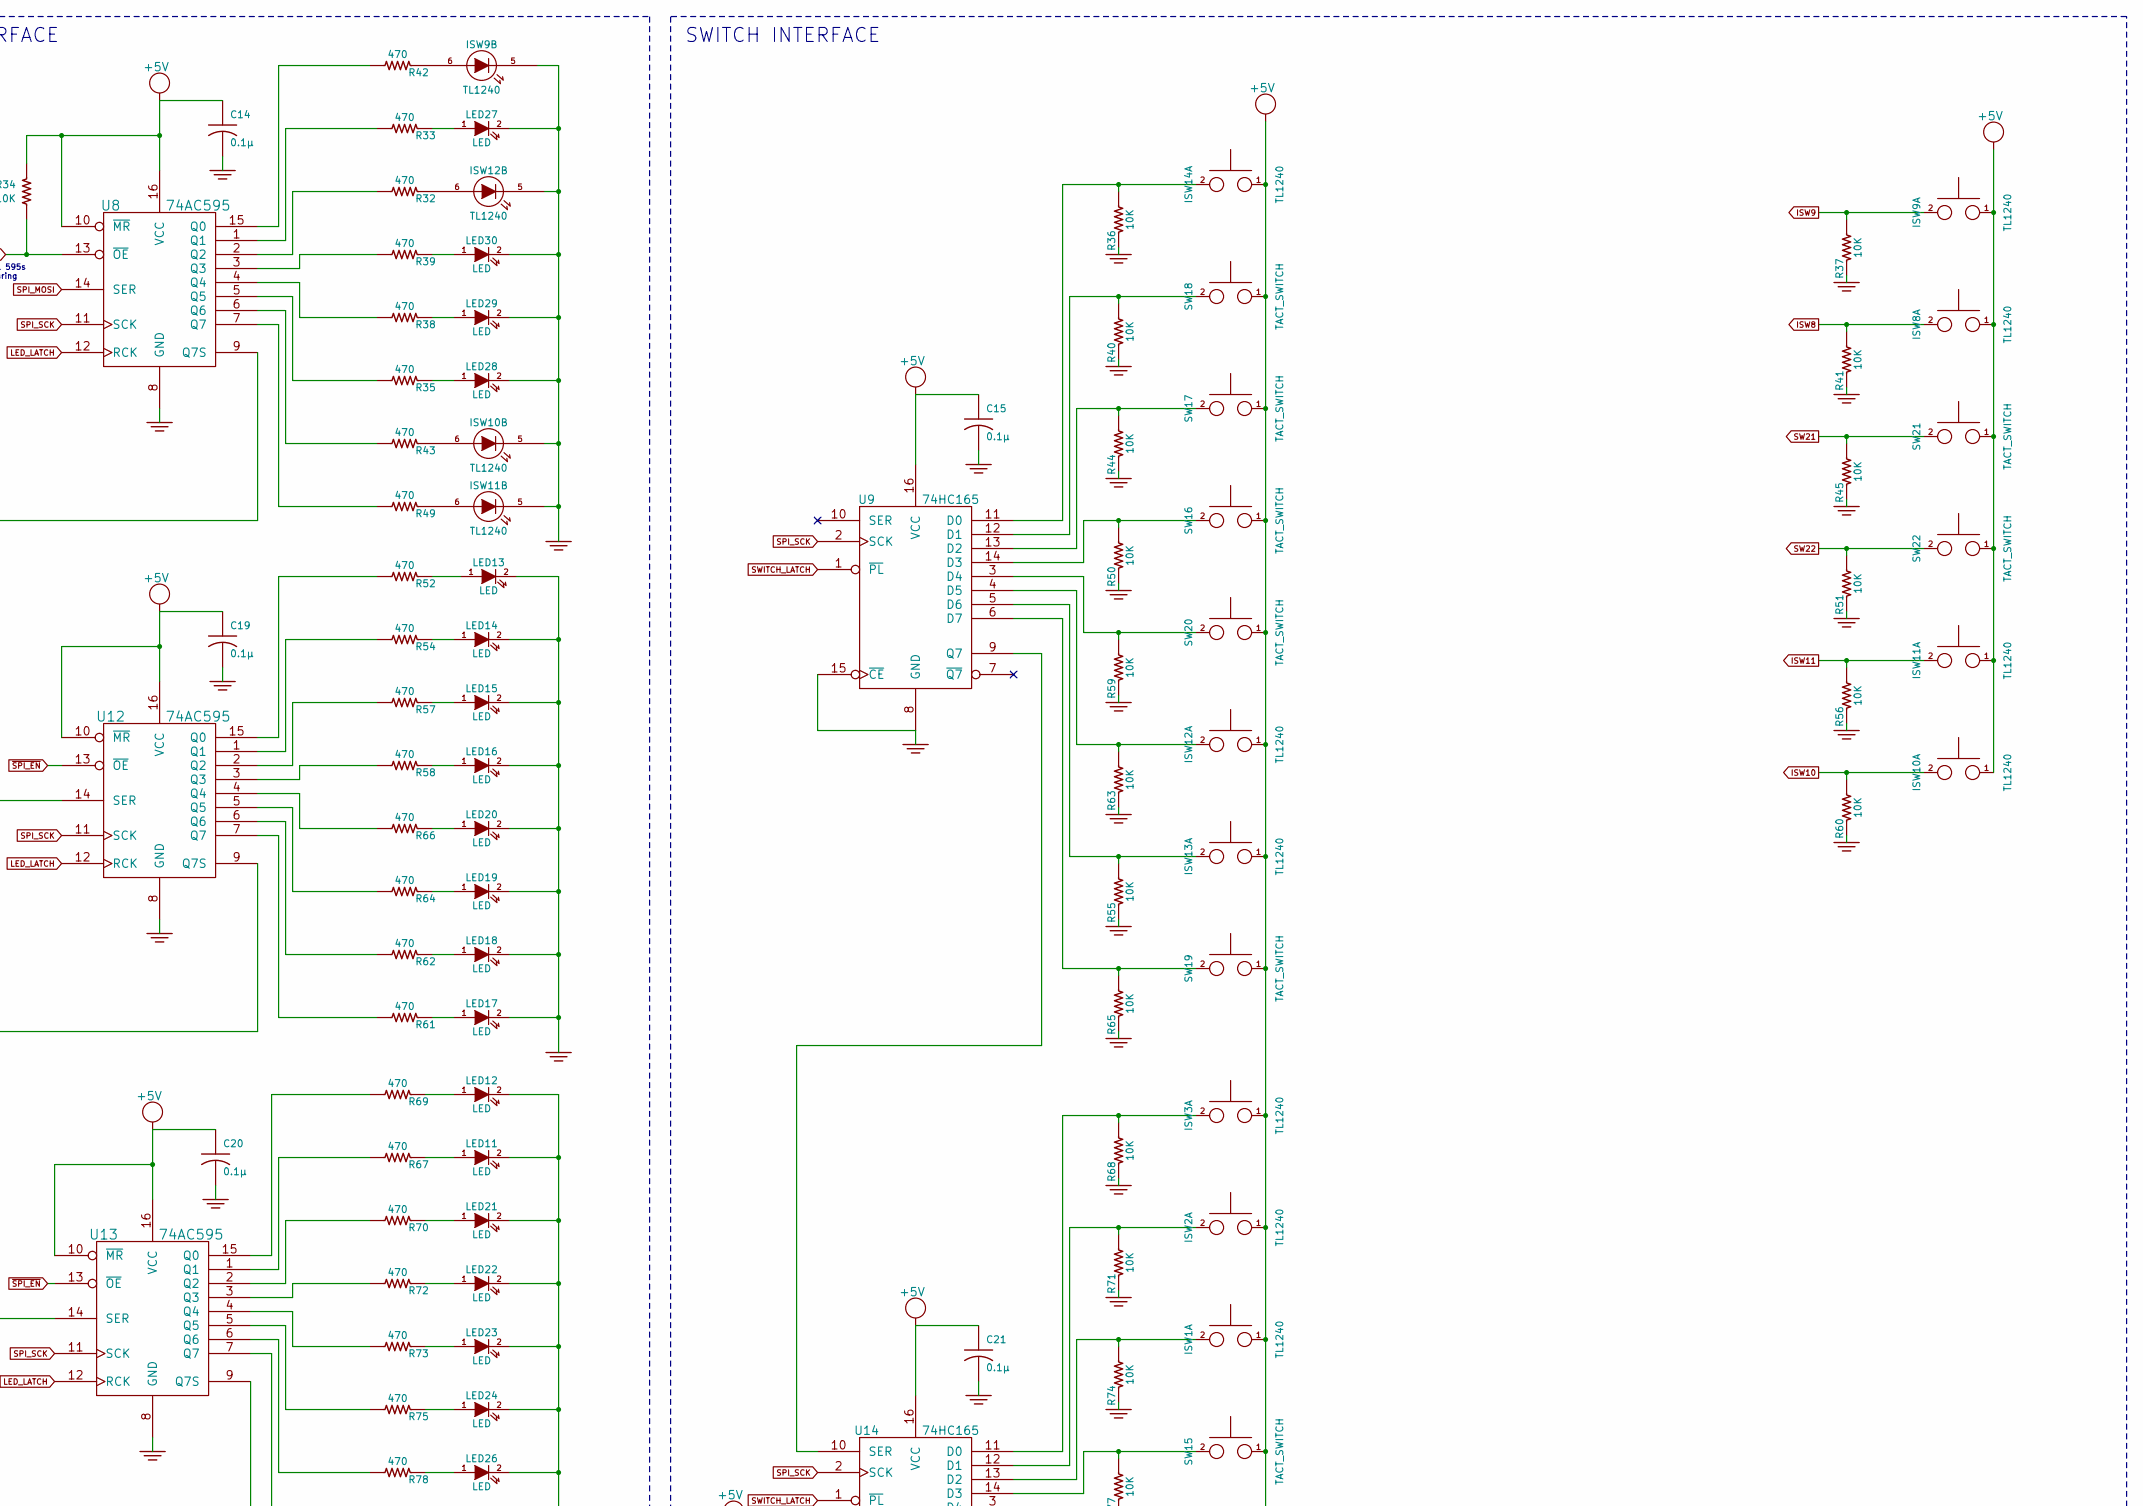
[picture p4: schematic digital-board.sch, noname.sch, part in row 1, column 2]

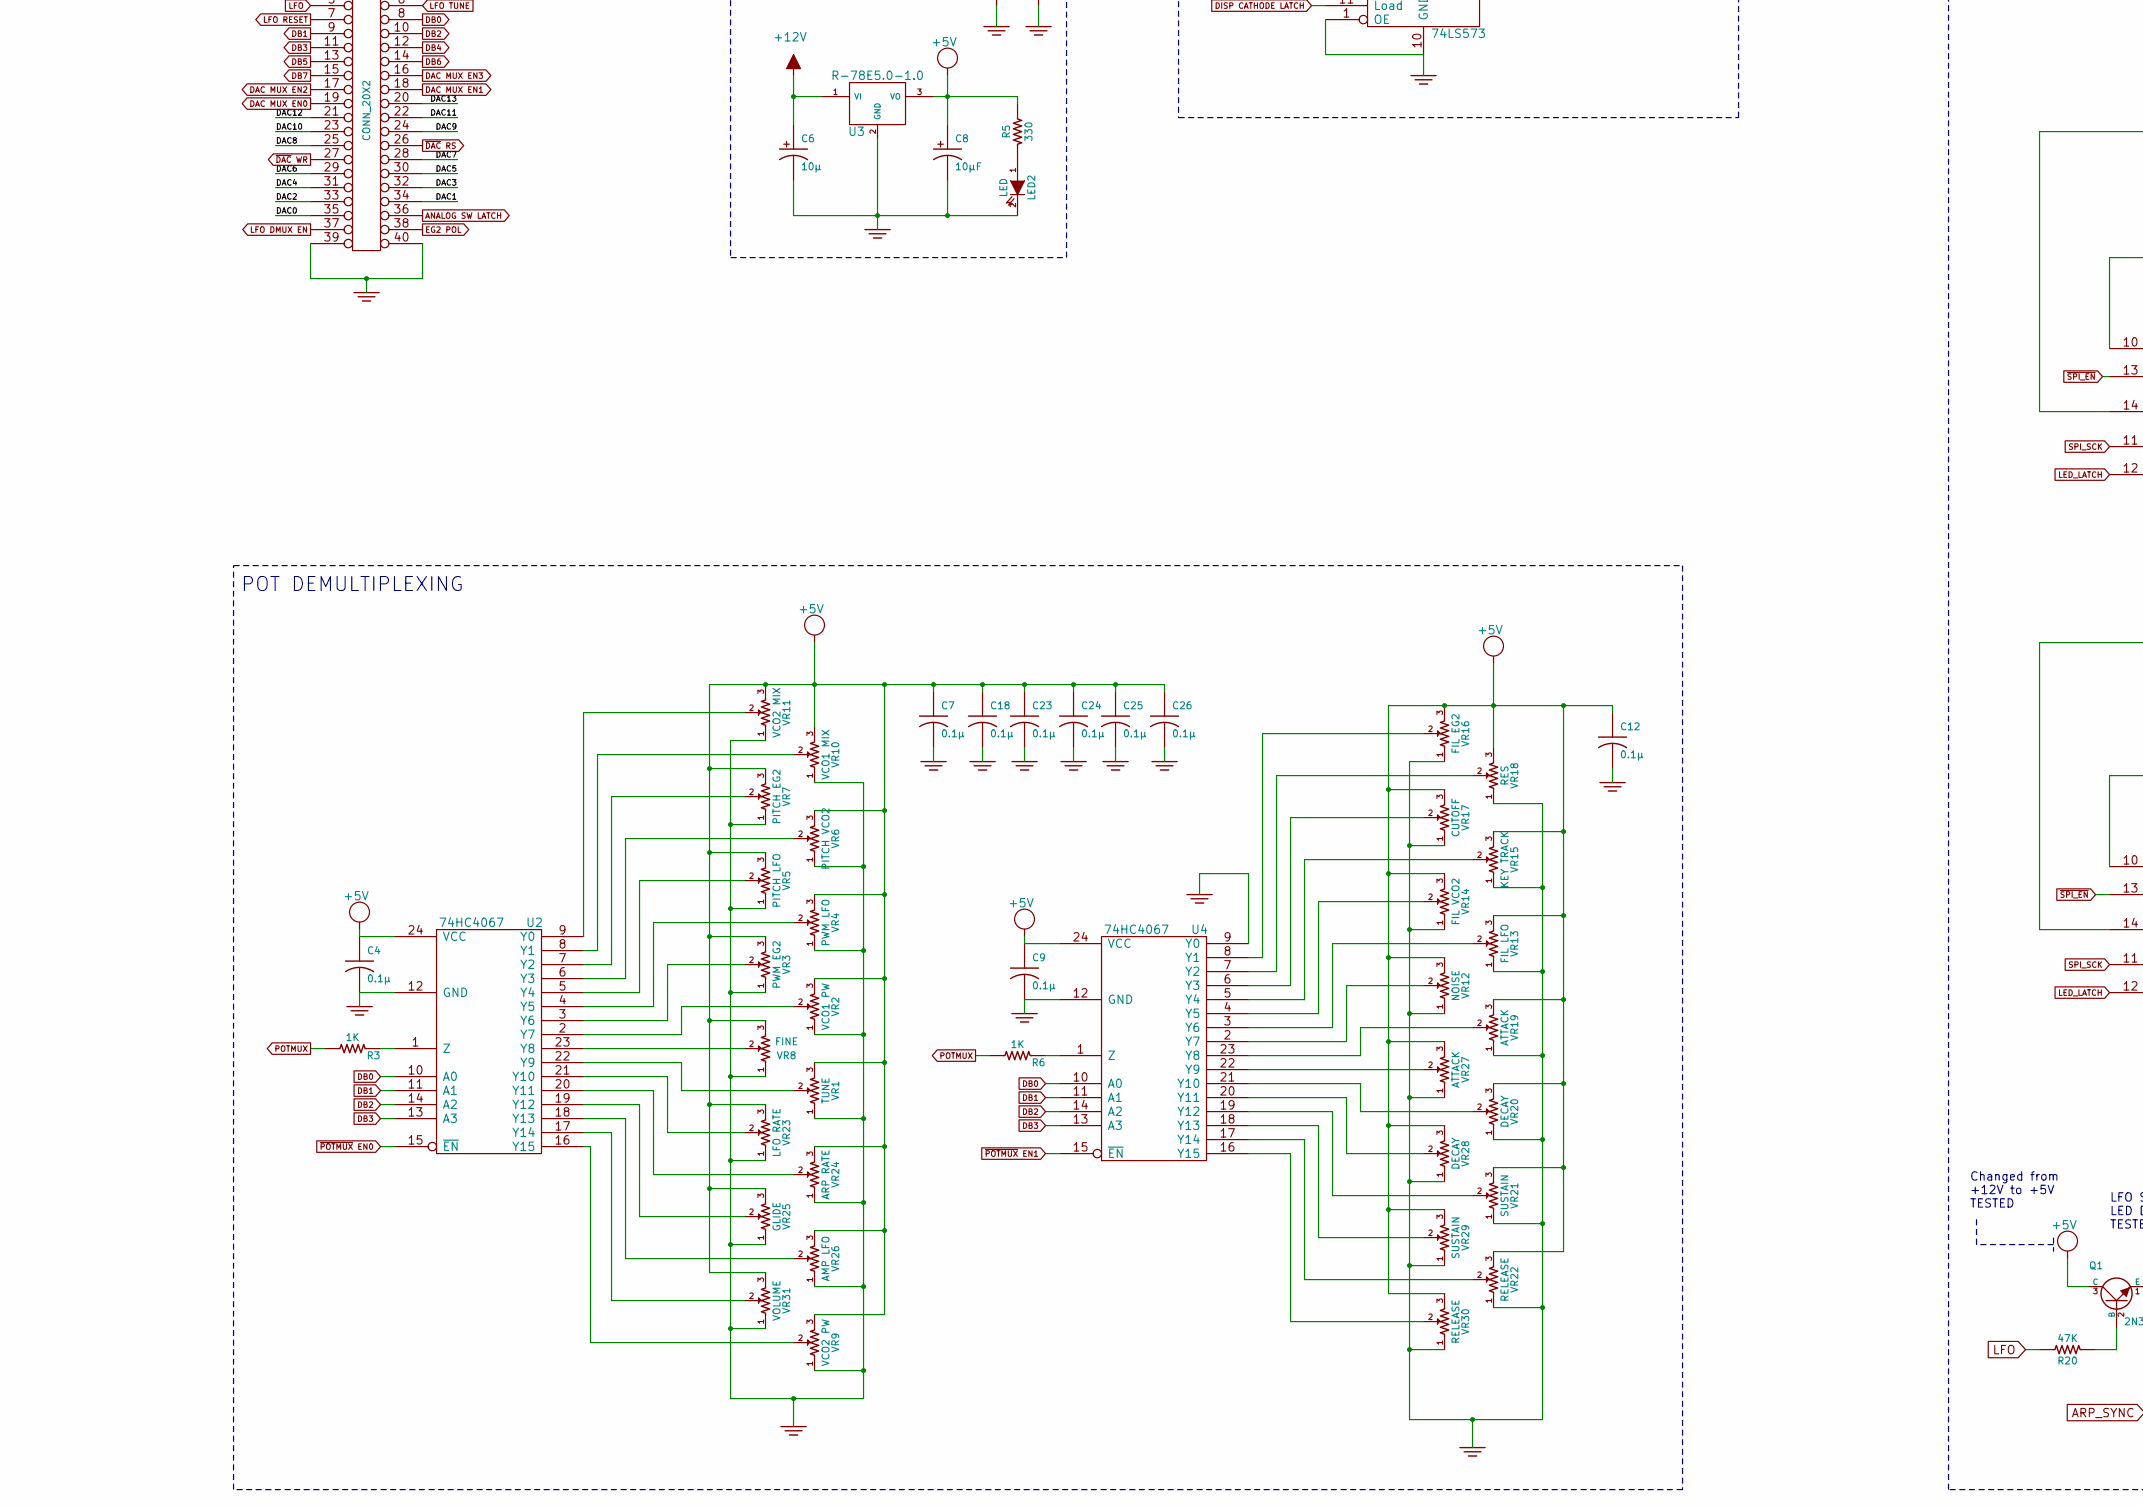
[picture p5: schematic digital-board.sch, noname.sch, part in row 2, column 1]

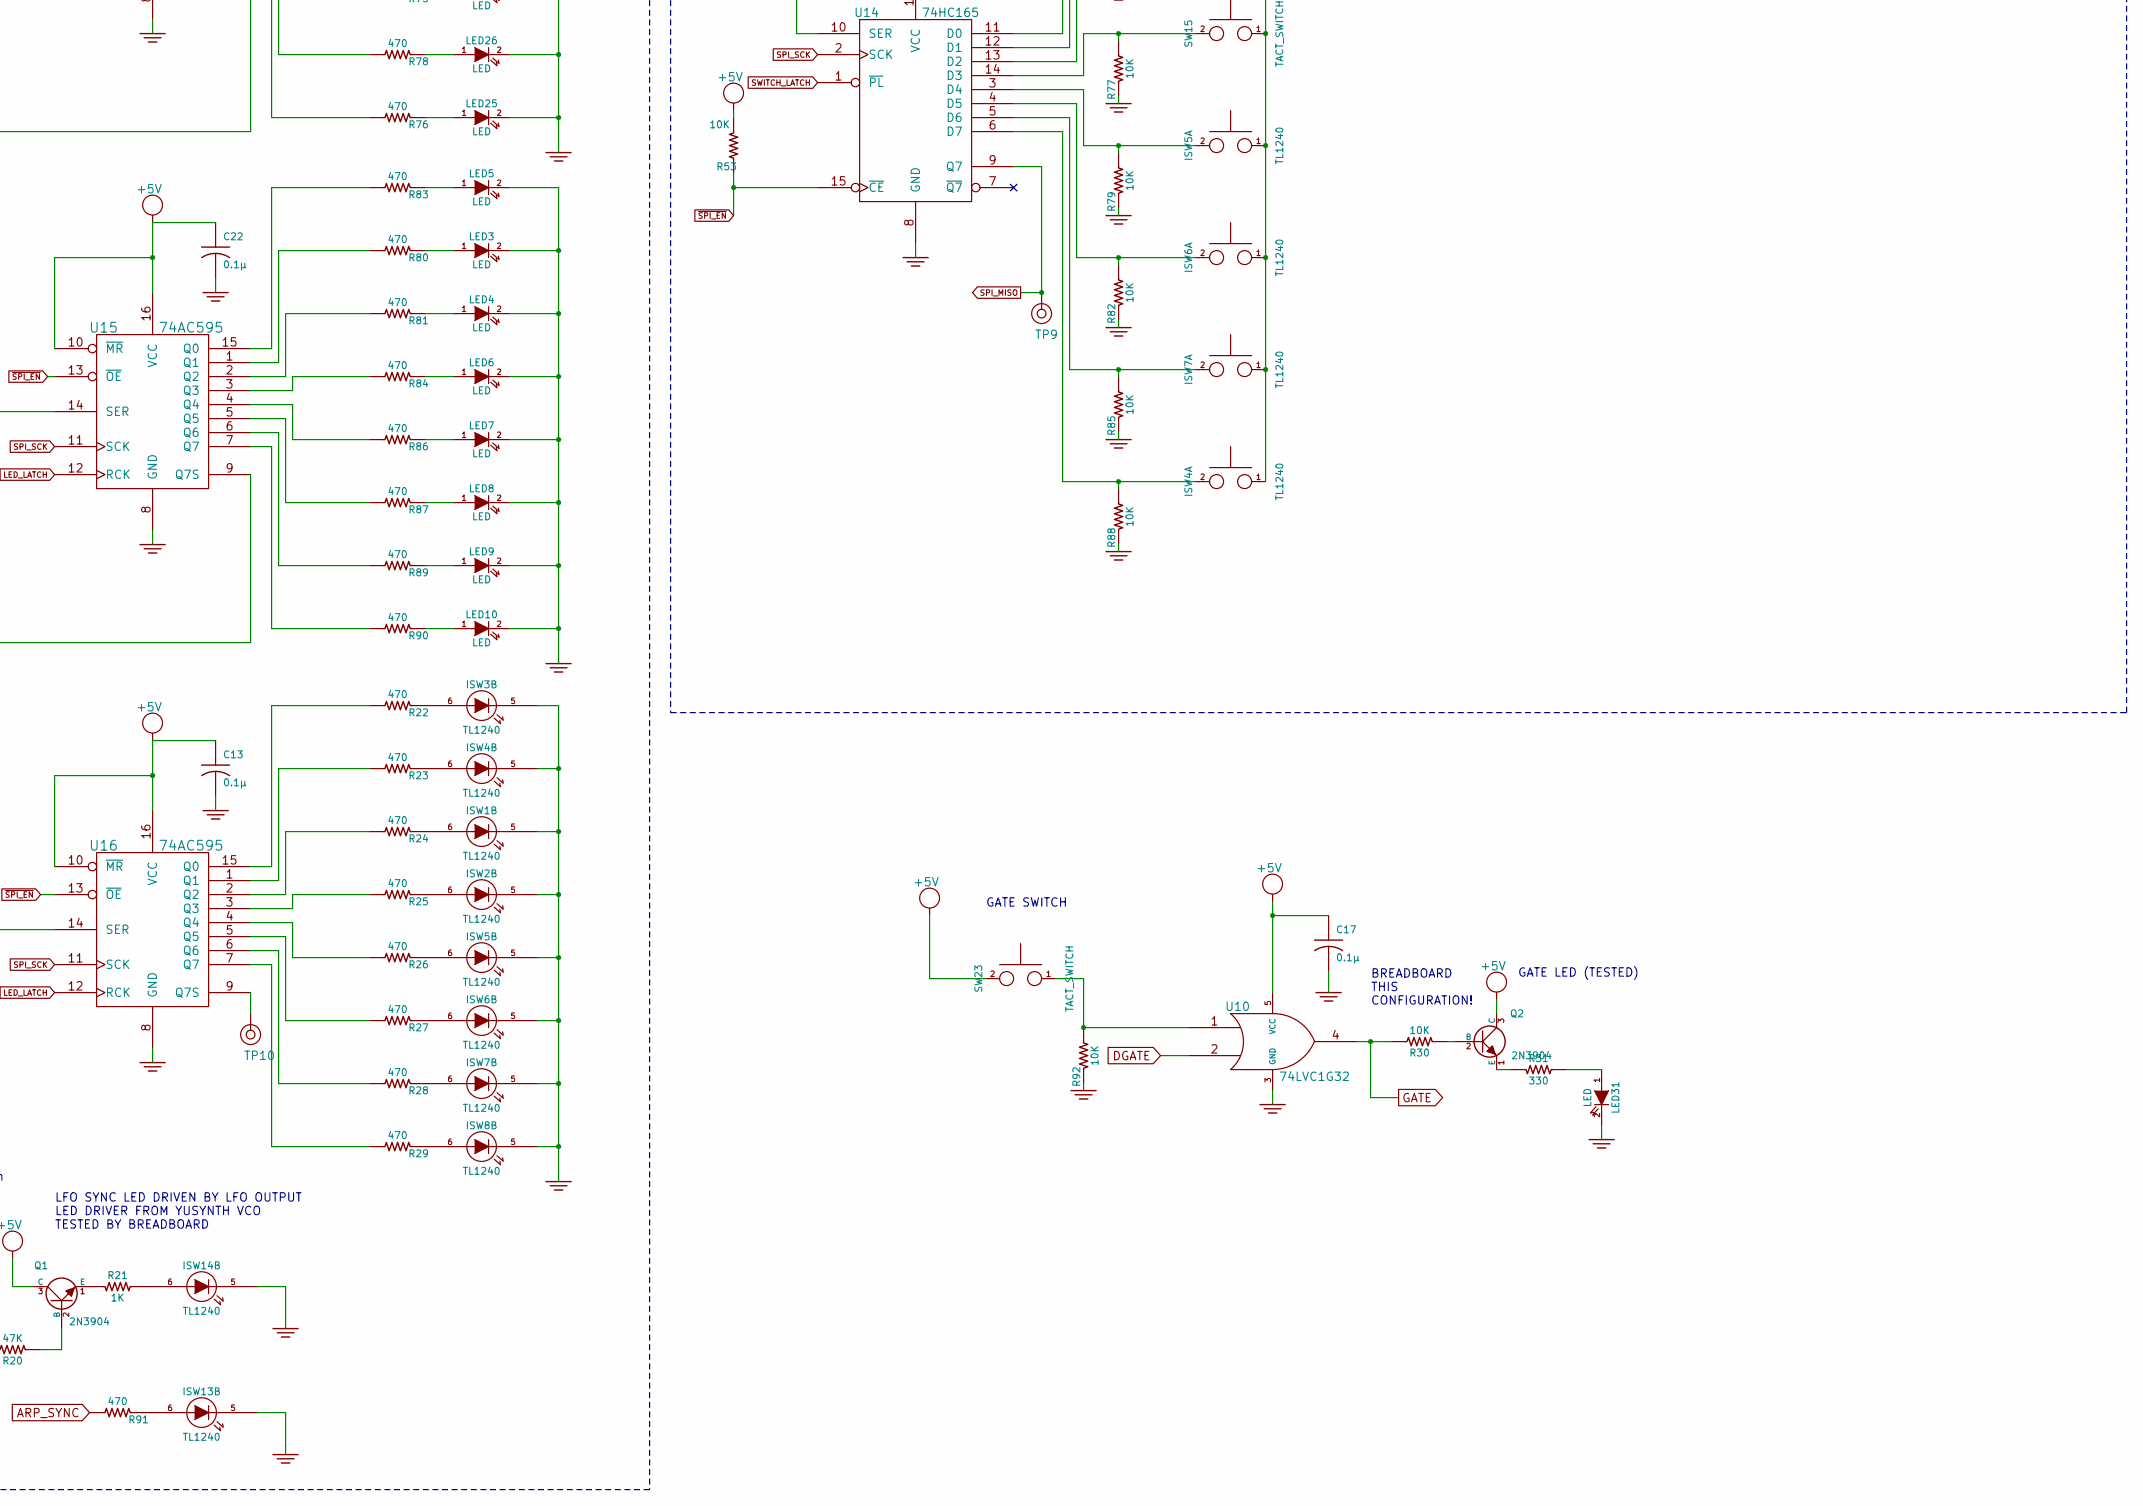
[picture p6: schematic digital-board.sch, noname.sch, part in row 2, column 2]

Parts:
C1, C4, C5, C7, C9, C10, C11, C12, C13, C14, C15, C16, C17, C18, C19, C20, C21, C22, C23, C24, C25, C26: 0.1µ
C2, C3: 24p
C6: 10µ
C8: 10µF
D1: 1N4148
DS1: LDQ-M286R1; 7-segment-4-digit
IC1: ATMEGA6450-A; TQFP100
ISP1: CONN_3X2
ISW1, ISW2, ISW3, ISW4, ISW5, ISW6, ISW7, ISW8, ISW9, ISW10, ISW11, ISW12, ISW13, ISW14: TL1240
J1: CONN_20X2
L1: 10µH
LED2, LED31: LED
LED3, LED4, LED5, LED6, LED7, LED8, LED9, LED10, LED11, LED12, LED13, LED14, LED15, LED16, LED17, LED18, LED19, LED20, LED21, LED22, LED23, LED24, LED25, LED26, LED27, LED28, LED29, LED30: LED
OC1: 6N137; optocoupler-DIL08
Q1, Q2: 2N3904
R1: 100K
R2, R3, R6, R46, R47, R48: 1K
R5, R31: 330
R7, R8, R13, R19: 220
R9, R22, R23, R24, R25, R26, R27, R28, R29, R32, R33, R35, R38, R39, R42, R43, R49, R52, R54, R57, R58, R61, R62, R64, R66, R67, R69, R70, R72, R73, R75, R76, R78, R80, R81, R83, R84, R86, R87, R89, R90, R91: 470
R10, R11, R12, R14, R15, R16, R17: 560
R18, R34, R36, R37, R40, R41, R44, R45, R50, R51, R53, R55, R56, R59, R60, R63, R65, R68, R71, R74, R77, R79, R82, R85, R88, R92: 10K
R20: 47K
R21: 1K
R30: 10K
SW15, SW16, SW17, SW18, SW19, SW20, SW21, SW22, SW23: TACT_SWITCH
TP1, TP2, TP9, TP10, TP12, TP13: CONN_1
TP11: CONN_1
U1: DG419
U2, U4: 74HC4067
U3: R-78E5.0-1.0
U5, U6: 74LS573
U7: 74LVC2G04
U8, U12, U13, U15, U16: 74AC595
U9, U14: 74HC165
U10: 74LVC1G32
VR1: TUNE
VR2: VCO1 PW
VR3: PWM EG2
VR4: PWM LFO
VR5: PITCH LFO
VR6: PITCH VCO2
VR7: PITCH EG2
VR8: FINE
VR9: VCO2 PW
VR10: VCO1 MIX
VR11: VCO2 MIX
VR12: NOISE
VR13: FIL LFO
VR14: FIL VCO2
VR15: KEY TRACK
VR16: FIL EG2
VR17: CUTOFF
VR18: RES
VR19, VR27: ATTACK
VR20, VR28: DECAY
VR21, VR29: SUSTAIN
VR22, VR30: RELEASE
VR23: LFO RATE
VR24: ARP RATE
VR25: GLIDE
VR26: AMP LFO
VR31: VOLUME
X1: MIDI OUT
X2: MIDI IN
X3: MIDI THRU
XTAL1: 20MHz

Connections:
+5V: C4.1, C7.1, C8.1 (+), C9.1, C10.1, C11.1, C12.1, C13.1, C14.1, C15.1, C16.1, C17.1, C18.1, C19.1, C20.1, C21.1, C22.1, C23.1, C24.1, C25.1, C26.1, IC1.10 (VCC), IC1.31 (VCC), IC1.80 (VCC), ISP1.2, ISW1.1, ISW2.1, ISW3.1, ISW4.1, ISW5.1, ISW6.1, ISW7.1, ISW8.1, ISW9.1, ISW10.1, ISW11.1, ISW12.1, ISW13.1, ISW14.1, L1.1, OC1.8, Q1.3 (C), Q2.3 (C), R1.1, R5.2, R8.1, R18.2, R19.1, R34.1, R53.1, SW15.1, SW16.1, SW17.1, SW18.1, SW19.1, SW20.1, SW21.1, SW22.1, SW23.2, U1.5 (VCC), U2.24 (VCC), U3.3 (VO), U4.24 (VCC), U5.20 (VCC), U6.20 (VCC), U7.5 (V+), U8.10 (~MR), U8.16 (VCC), U9.16 (VCC), U10.5 (VCC), U12.10 (~MR), U12.16 (VCC), U13.10 (~MR), U13.16 (VCC), U14.16 (VCC), U15.10 (~MR), U15.16 (VCC), U16.10 (~MR), U16.16 (VCC), VR1.3, VR2.3, VR3.3, VR4.3, VR5.3, VR6.3, VR7.3, VR8.3, VR9.3, VR10.3, VR11.3, VR12.3, VR13.3, VR14.3, VR15.3, VR16.3, VR17.3, VR18.3, VR19.3, VR20.3, VR21.3, VR22.3, VR23.3, VR24.3, VR25.3, VR26.3, VR27.3, VR28.3, VR29.3, VR30.3, VR31.3
+12V: C6.1 (+), J1.1, J1.2, U1.4 (V+), U3.1 (VI)
/DAC0: IC1.43 ((ICP1)PD0), J1.35
/DAC1: IC1.44 ((INT0)PD1), J1.34
/DAC2: IC1.45 (PD2), J1.33
/DAC3: IC1.46 (PD3), J1.32
/DAC4: IC1.47 (PD4), J1.31
/DAC5: IC1.48 (PD5), J1.30
/DAC6: IC1.49 (PD6), J1.29
/DAC7: IC1.50 (PD7), J1.28
/DAC8: IC1.53 (PC0), J1.25
/DAC9: IC1.54 (PC1), J1.24
/DAC10: IC1.55 (PC2), J1.23
/DAC11: IC1.56 (PC3), J1.22
/DAC12: IC1.57 (PC4), J1.21
/DAC13: IC1.58 (PC5), J1.20
ANALOG SW LATCH: IC1.41 (PJ6(PCINT30)), J1.36
ARP_SYNC: IC1.26 ((PCINT15/OC2A)PB7), R91.2
DAC MUX EN0: IC1.63 (PH0(PCINT16)), J1.19
DAC MUX EN1: IC1.64 (PH1(PCINT17)), J1.18
DAC MUX EN2: IC1.65 (PH2(PCINT18)), J1.17
DAC MUX EN3: IC1.66 (PH3(PCINT19)), J1.16
DB0: IC1.78 (PA0), J1.8, U2.10 (A0), U4.10 (A0), U5.2 (D0), U6.2 (D0)
DB1: IC1.77 (PA1), J1.9, U2.11 (A1), U4.11 (A1), U5.3 (D1), U6.3 (D1)
DB2: IC1.76 (PA2), J1.10, U2.14 (A2), U4.14 (A2), U5.4 (D2), U6.4 (D2)
DB3: IC1.75 (PA3), J1.11, U2.13 (A3), U4.13 (A3), U5.5 (D3), U6.5 (D3)
DB4: IC1.74 (PA4), J1.12, U6.6 (D4)
DB5: IC1.73 (PA5), J1.13, U6.7 (D5)
DB6: IC1.72 (PA6), J1.14, U6.8 (D6)
DB7: IC1.71 (PA7), J1.15, U6.9 (D7)
DGATE: IC1.96 (PF1(ADC1)), U10.2
DISP ANODE LATCH: IC1.85 (PH5(PCINT21)), U5.11 (Load)
DISP CATHODE LATCH: IC1.84 (PH4(PCINT20)), U6.11 (Load)
EG2 POL: IC1.39 (PJ4(PCINT28)), J1.38
FREQ IN: IC1.29 (PG4(T0)), R2.1, TP12.1
GATE: J1.3, R30.2, U10.4
ISW8: IC1.95 (PF2(ADC2)), ISW8.2, R41.2
ISW9: IC1.94 (PF3(ADC3)), ISW9.2, R37.2
ISW10: IC1.90 (PF7(ADC7/TDI)), ISW10.2, R60.2
ISW11: IC1.93 (PF4(ADC4/TCK)), ISW11.2, R56.2
LED_LATCH: IC1.38 (PJ3(PCINT27)), U8.12 (RCK), U12.12 (RCK), U13.12 (RCK), U15.12 (RCK), U16.12 (RCK)
LFO: J1.5, R20.2
LFO DMUX EN: IC1.40 (PJ5(PCINT29)), J1.37
LFO RESET: IC1.23 ((PCINT12/OC0A)PB4), J1.7
LFO TUNE: J1.6, U1.8 (A)
MISO: IC1.22 ((PCINT11/MISO)PB3), ISP1.1, R48.2
MOSI: IC1.21 ((PCINT10/MOSI)PB2), ISP1.4, R47.2
unnamed: C1.1, IC1.98 (AREF)
unnamed: C2.2, IC1.33 (XTAL2(TOSC2)), XTAL1.2
unnamed: C3.2, IC1.34 (XTAL1(TOSC1)), TP11.1, XTAL1.1
unnamed: C5.1, IC1.100 (AVCC), L1.2
unnamed: D1.1 (A), OC1.3, X2.5
unnamed: D1.2 (K), OC1.2, R7.1
unnamed: DS1.1 (e), R14.1
unnamed: DS1.2 (d), R12.1
unnamed: DS1.3 (dp), R17.1
unnamed: DS1.4 (c), R11.1
unnamed: DS1.5 (g), R16.1
unnamed: DS1.6 (A3), U5.16 (Q3)
unnamed: DS1.7 (b), R10.1
unnamed: DS1.8 (A2), U5.19 (Q0)
unnamed: DS1.9 (A1), U5.18 (Q1)
unnamed: DS1.10 (f), R15.1
unnamed: DS1.11 (a), R9.1
unnamed: DS1.12 (A0), U5.17 (Q2)
unnamed: IC1.28 (PG3(T1)), TP13.1
unnamed: ISW1.2, R74.2, U14.13 (D2)
unnamed: ISW1.6 (A), R24.1
unnamed: ISW2.2, R71.2, U14.12 (D1)
unnamed: ISW2.6 (A), R25.1
unnamed: ISW3.2, R68.2, U14.11 (D0)
unnamed: ISW3.6 (A), R22.1
unnamed: ISW4.2, R88.2, U14.6 (D7)
unnamed: ISW4.6 (A), R23.1
unnamed: ISW5.2, R79.2, U14.3 (D4)
unnamed: ISW5.6 (A), R26.1
unnamed: ISW6.2, R82.2, U14.4 (D5)
unnamed: ISW6.6 (A), R27.1
unnamed: ISW7.2, R85.2, U14.5 (D6)
unnamed: ISW7.6 (A), R28.1
unnamed: ISW8.6 (A), R29.1
unnamed: ISW9.6 (A), R42.1
unnamed: ISW10.6 (A), R43.1
unnamed: ISW11.6 (A), R49.1
unnamed: ISW12.2, R63.2, U9.4 (D5)
unnamed: ISW12.6 (A), R32.1
unnamed: ISW13.2, R55.2, U9.5 (D6)
unnamed: ISW13.6 (A), R91.1
unnamed: ISW14.2, R36.2, U9.11 (D0)
unnamed: ISW14.6 (A), R21.2
unnamed: LED2.1 (A), R5.1
unnamed: LED3.1 (A), R80.1
unnamed: LED4.1 (A), R81.1
unnamed: LED5.1 (A), R83.1
unnamed: LED6.1 (A), R84.1
unnamed: LED7.1 (A), R86.1
unnamed: LED8.1 (A), R87.1
unnamed: LED9.1 (A), R89.1
unnamed: LED10.1 (A), R90.1
unnamed: LED11.1 (A), R67.1
unnamed: LED12.1 (A), R69.1
unnamed: LED13.1 (A), R52.1
unnamed: LED14.1 (A), R54.1
unnamed: LED15.1 (A), R57.1
unnamed: LED16.1 (A), R58.1
unnamed: LED17.1 (A), R61.1
unnamed: LED18.1 (A), R62.1
unnamed: LED19.1 (A), R64.1
unnamed: LED20.1 (A), R66.1
unnamed: LED21.1 (A), R70.1
unnamed: LED22.1 (A), R72.1
unnamed: LED23.1 (A), R73.1
unnamed: LED24.1 (A), R75.1
unnamed: LED25.1 (A), R76.1
unnamed: LED26.1 (A), R78.1
unnamed: LED27.1 (A), R33.1
unnamed: LED28.1 (A), R35.1
unnamed: LED29.1 (A), R38.1
unnamed: LED30.1 (A), R39.1
unnamed: LED31.1 (A), R31.2
unnamed: Q1.1 (E), R21.1
unnamed: Q1.2 (B), R20.1
unnamed: Q2.1 (E), R31.1
unnamed: Q2.2 (B), R30.1
unnamed: R2.2, U1.1 (COM)
unnamed: R3.1, U2.1 (Z)
unnamed: R6.1, U4.1 (Z)
unnamed: R7.2, X2.4
unnamed: R8.2, X1.4
unnamed: R9.2, U6.17 (Q2)
unnamed: R10.2, U6.19 (Q0)
unnamed: R11.2, U6.15 (Q4)
unnamed: R12.2, U6.13 (Q6)
unnamed: R13.1, X3.5
unnamed: R13.2, U7.4
unnamed: R14.2, U6.12 (Q7)
unnamed: R15.2, U6.18 (Q1)
unnamed: R16.2, U6.16 (Q3)
unnamed: R17.2, U6.14 (Q5)
unnamed: R19.2, X3.4
unnamed: R22.2, U16.15 (Q0)
unnamed: R23.2, U16.1 (Q1)
unnamed: R24.2, U16.2 (Q2)
unnamed: R25.2, U16.3 (Q3)
unnamed: R26.2, U16.4 (Q4)
unnamed: R27.2, U16.5 (Q5)
unnamed: R28.2, U16.6 (Q6)
unnamed: R29.2, U16.7 (Q7)
unnamed: R32.2, U8.2 (Q2)
unnamed: R33.2, U8.1 (Q1)
unnamed: R35.2, U8.5 (Q5)
unnamed: R38.2, U8.4 (Q4)
unnamed: R39.2, U8.3 (Q3)
unnamed: R40.2, SW18.2, U9.12 (D1)
unnamed: R42.2, U8.15 (Q0)
unnamed: R43.2, U8.6 (Q6)
unnamed: R44.2, SW17.2, U9.13 (D2)
unnamed: R49.2, U8.7 (Q7)
unnamed: R50.2, SW16.2, U9.14 (D3)
unnamed: R52.2, U12.15 (Q0)
unnamed: R54.2, U12.1 (Q1)
unnamed: R57.2, U12.2 (Q2)
unnamed: R58.2, U12.3 (Q3)
unnamed: R59.2, SW20.2, U9.3 (D4)
unnamed: R61.2, U12.7 (Q7)
unnamed: R62.2, U12.6 (Q6)
unnamed: R64.2, U12.5 (Q5)
unnamed: R65.2, SW19.2, U9.6 (D7)
unnamed: R66.2, U12.4 (Q4)
unnamed: R67.2, U13.1 (Q1)
unnamed: R69.2, U13.15 (Q0)
unnamed: R70.2, U13.2 (Q2)
unnamed: R72.2, U13.3 (Q3)
unnamed: R73.2, U13.4 (Q4)
unnamed: R75.2, U13.5 (Q5)
unnamed: R76.2, U13.7 (Q7)
unnamed: R77.2, SW15.2, U14.14 (D3)
unnamed: R78.2, U13.6 (Q6)
unnamed: R80.2, U15.1 (Q1)
unnamed: R81.2, U15.2 (Q2)
unnamed: R83.2, U15.15 (Q0)
unnamed: R84.2, U15.3 (Q3)
unnamed: R86.2, U15.4 (Q4)
unnamed: R87.2, U15.5 (Q5)
unnamed: R89.2, U15.6 (Q6)
unnamed: R90.2, U15.7 (Q7)
unnamed: R92.2, SW23.1, U10.1
unnamed: TP10.1, U16.9 (Q7S)
unnamed: U2.2 (Y7), VR2.2
unnamed: U2.3 (Y6), VR3.2
unnamed: U2.4 (Y5), VR4.2
unnamed: U2.5 (Y4), VR5.2
unnamed: U2.6 (Y3), VR6.2
unnamed: U2.7 (Y2), VR7.2
unnamed: U2.8 (Y1), VR10.2
unnamed: U2.9 (Y0), VR11.2
unnamed: U2.16 (Y15), VR9.2
unnamed: U2.17 (Y14), VR31.2
unnamed: U2.18 (Y13), VR26.2
unnamed: U2.19 (Y12), VR25.2
unnamed: U2.20 (Y11), VR24.2
unnamed: U2.21 (Y10), VR23.2
unnamed: U2.22 (Y9), VR1.2
unnamed: U2.23 (Y8), VR8.2
unnamed: U4.2 (Y7), VR12.2
unnamed: U4.3 (Y6), VR13.2
unnamed: U4.4 (Y5), VR14.2
unnamed: U4.5 (Y4), VR15.2
unnamed: U4.6 (Y3), VR17.2
unnamed: U4.7 (Y2), VR18.2
unnamed: U4.8 (Y1), VR16.2
unnamed: U4.16 (Y15), VR30.2
unnamed: U4.17 (Y14), VR22.2
unnamed: U4.18 (Y13), VR29.2
unnamed: U4.19 (Y12), VR21.2
unnamed: U4.20 (Y11), VR28.2
unnamed: U4.21 (Y10), VR20.2
unnamed: U4.22 (Y9), VR27.2
unnamed: U4.23 (Y8), VR19.2
unnamed: U7.3, U7.6
unnamed: U12.9 (Q7S), U13.14 (SER)
unnamed: U8.9 (Q7S), U12.14 (SER)
unnamed: U13.9 (Q7S), U15.14 (SER)
unnamed: U9.9 (Q7), U14.10 (SER)
unnamed: U15.9 (Q7S), U16.14 (SER)
POTMUX: IC1.97 (PF0(ADC0)), R3.2, R6.2
SCK: IC1.20 ((PCINT9/SCK)PB1), ISP1.3, R46.2
SPI_MISO: R48.1, TP9.1, U14.9 (Q7)
SPI_MOSI: R47.1, U8.14 (SER)
SPI_SCK: R46.1, U8.11 (SCK), U9.2 (SCK), U12.11 (SCK), U13.11 (SCK), U14.2 (SCK), U15.11 (SCK), U16.11 (SCK)
SW21: IC1.91 (PF6(ADC6/TDO)), R45.2, SW21.2
SW22: IC1.92 (PF5(ADC5/TMS)), R51.2, SW22.2
SWITCH_LATCH: IC1.24 ((PCINT13/OC1A)PB5), U9.1 (~PL), U14.1 (~PL)
TUNE: J1.4, U1.2 (B)
TUNE SEL: IC1.70 (PG2), U1.6 (A/B)
UART RX: IC1.2 ((PCINT0/RXD)PE0), OC1.6, R18.1, U7.1
UART TX: IC1.3 ((PCINT1/TXD)PE1), X1.5
~DAC RS: IC1.52 (PG1), J1.26
~DAC WR: IC1.51 (PG0), J1.27
~POTMUX EN0: IC1.86 (PH6(PCINT22)), U2.15 (~EN)
~POTMUX EN1: IC1.87 (PH7(PCINT23)), U4.15 (~EN)
~RESET: IC1.30 (PG5(~RESET~)), ISP1.5, R1.2
~SPI_EN: IC1.37 (PJ2(PCINT26)), R34.2, R53.2, U8.13 (~OE), U12.13 (~OE), U13.13 (~OE), U14.15 (~CE), U15.13 (~OE), U16.13 (~OE)

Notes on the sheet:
LFO SYNC LED DRIVEN BY LFO OUTPUT LED DRIVER FROM YUSYNTH VCO TESTED BY BREADBOARD
LFO CLOCK - WHICH TIMER 8 BIT or 16 BIT?
MIDI INTERFACE
POT DEMULTIPLEXING
LED DISPLAY
LED INTERFACE
SWITCH INTERFACE
MCU
+5V DIGITAL SUPPLY REGULATOR
GATE LED (TESTED)
GATE SWITCH
BREADBOARD THIS CONFIGURATION!
SPI_EN added to all 595s to keep LEDs off during MCU boot
DAC BUS
Changed from +12V to +5V TESTED

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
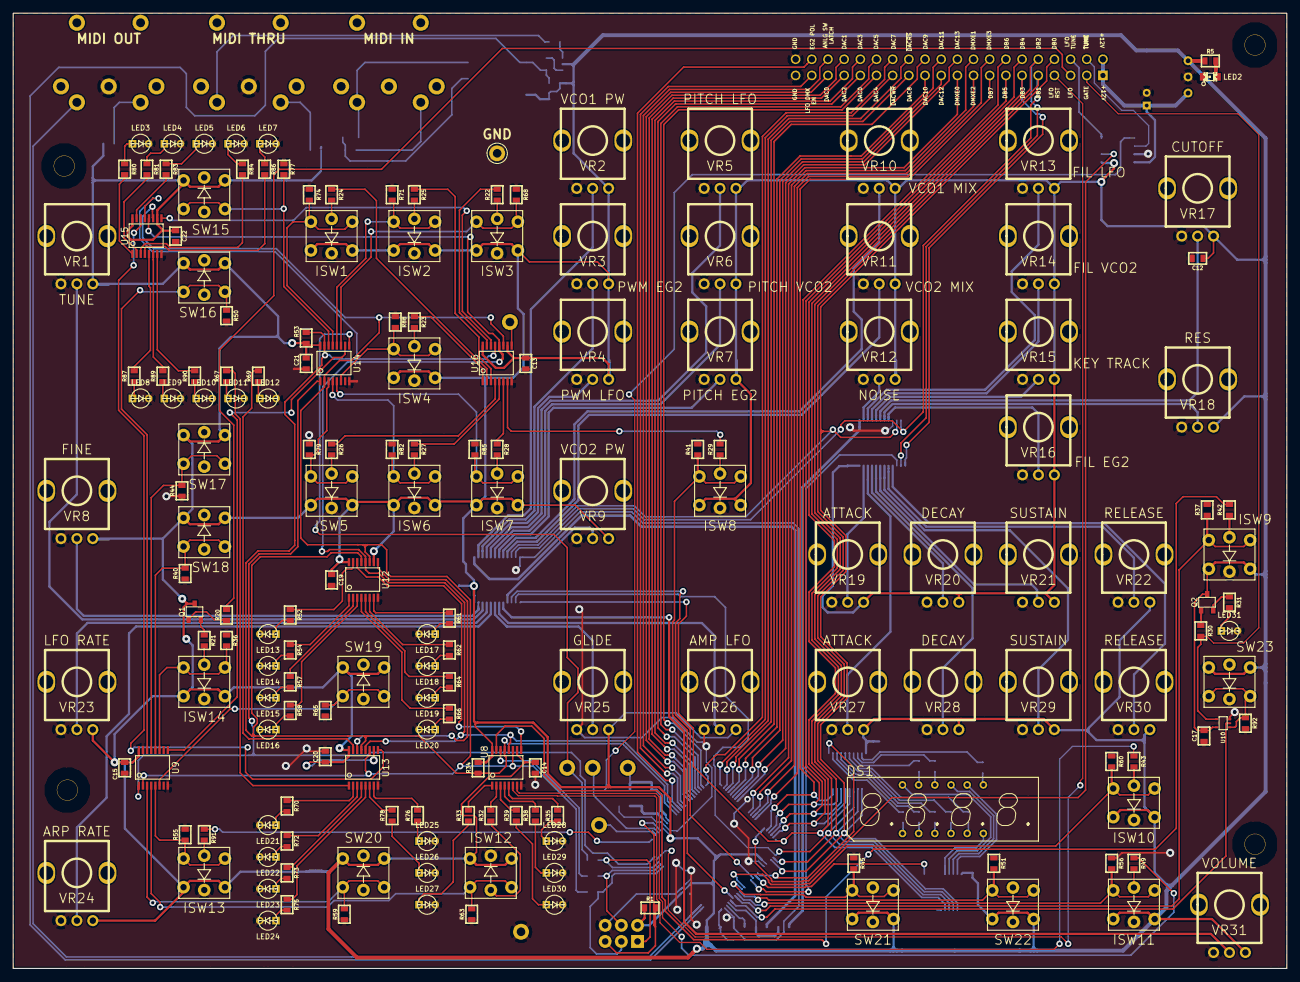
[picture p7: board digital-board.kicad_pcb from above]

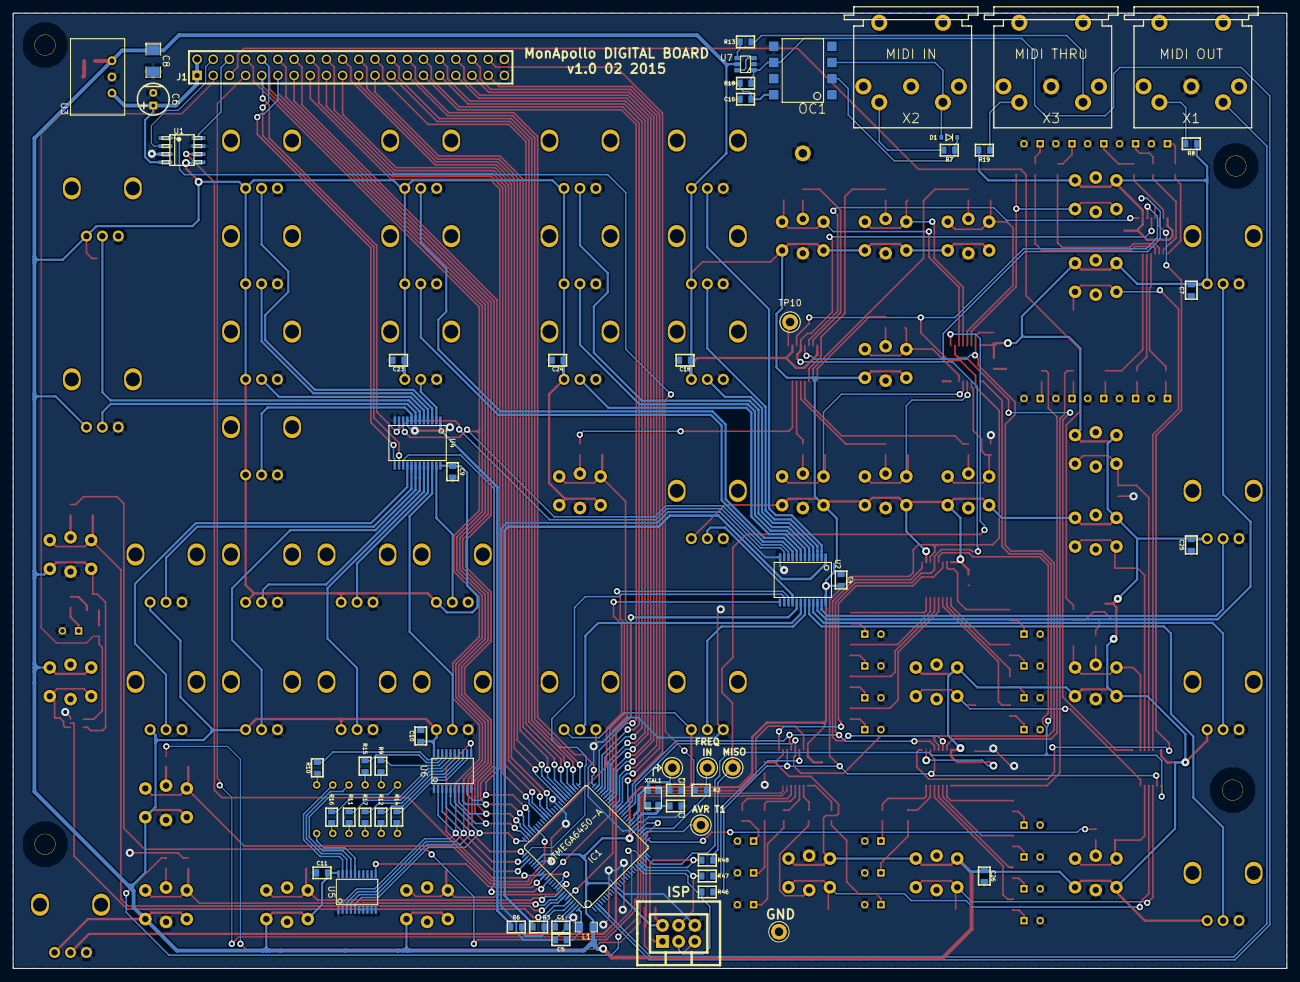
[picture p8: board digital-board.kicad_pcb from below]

Board: 2 copper layers, 200.0 x 150.0 mm, 240 parts (59 on the bottom side), 244 nets.

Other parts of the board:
HOLE-0.125-INCH, HOLE-0.125-INCH#2, HOLE-0.125-INCH#3, HOLE-0.125-INCH#4: VAL**; HOLE-0.125-INCH

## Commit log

2014-12-28 assigning footprints to digital board - in progress
    [digital-board.sch]
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2015-01-07 laying out board with led rework changes
    [digital-board.kicad_pcb, digital-board.sch]
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2015-01-12 bah problems with dsn export
    [digital-board.dsn, digital-board.kicad_pcb, digital-board.sch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]
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2015-01-13 working on fixing DSN mess - mu symbols were the problem
    [digital-board.dsn, spectra-test.dsn]
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2015-01-16 working on J1 and MCU connections for optimal routing
    [digital-board.kicad_pcb, digital-board.sch]
2015-01-17 almost done routing DAC and DATABUS to J1
    [digital-board.kicad_pcb, digital-board.sch]
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2015-01-21 autorouter almost done - just need to fix short complete traces to MCU
    [digital-board.dsn, digital-board.kicad_pcb]
2015-01-21 more routing before autorouting. can't fix short trace incompletes on MCU pins
    [digital-board.dsn, digital-board.kicad_pcb]
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2015-01-29 last save before silk screen edit in 5112
    [digital-board.kicad_pcb]
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2015-01-31 fixed Alpha pot footprint
    [digital-board.kicad_pcb]
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2015-02-11 finishing off silkscreen text, need to add GND test point
    [digital-board.kicad_pcb]
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2015-02-13 routing, silkscreen and tweaking done, about to try to change SPI_EN on 595s
    [digital-board.kicad_pcb]
2015-02-14 just adding 5112 gerbers. 5365 gerber output has drill hole bug
    [digital-board-B_Cu.gbl, digital-board-B_Mask.gbs, digital-board-B_SilkS.gbo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]
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2015-02-20 analog board component placement. problem with tssop-14 footprint. public kicad github repository seems to have dropped this footprint
    [analog-board.kicad_pcb, analog-board.sch]
2015-02-21 updated D2PAK footprints, fixed missing TSSOP-14 footprint
    [analog-board.kicad_pcb, analog-board.sch]
2015-02-22 starting to route, still need to place S&H buffers. VCO1 and VCO2 outputs to DG212s need to be swapped for better layout
    [analog-board.kicad_pcb, analog-board.sch]
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2015-02-26 moved audio jack, about to move DAC dmuxers and S&H components
    [analog-board.kicad_pcb, analog-board.sch]
2015-02-26 routing, moving stuff around to redo DAC demux placement and routing and S&H placement and routing
    [analog-board.kicad_pcb]
2015-02-27 moved S&H and DAC demuxers, routed 16 of 32 CVs
    [analog-board.kicad_pcb, analog-board.sch]
2015-03-02 routed all CVs still need to route EG1 EG2 S&Hs
    [analog-board.kicad_pcb]
2015-03-02 component placement done. need to add more bypass caps and route power traces
    [analog-board.kicad_pcb, analog-board.sch]
2015-03-03 added decoupling caps for op amps, need one more pair. started routing power. Oh boy...
    [analog-board.kicad_pcb, analog-board.sch]
2015-03-04 almost done routing pos and neg 12V power traces, but 5V traces are provign difficult. Going to branch now and start over again routing power traces first
    [analog-board.kicad_pcb, analog-board.sch]
2015-03-04 pulled up all traces, made a few minor placement changes, will now start routing power traces
    [analog-board.kicad_pcb]
2015-03-04 starting routing 12V power traces bus style, linking throughhole trimmer pins
    [analog-board.kicad_pcb]
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2015-03-06 routing LFO-NOISE-S&H
    [analog-board.kicad_pcb]
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2015-03-07 routing S&H CV traces. Need to move U14 over to the left to shorten 7 out of 8 CV traces
    [analog-board.kicad_pcb, analog-board.sch]
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2015-03-10 all CVs routed, just need to adjust EG1 and EG2 CVs
    [analog-board.kicad_pcb]
2015-03-10 flippled main 40 pin connector to work with connector on digital board - reconnected all traces
    [analog-board.kicad_pcb]
2015-03-12 getting close to finishing routing signal and power traces
    [analog-board.kicad_pcb, analog-board.sch]
2015-03-13 all power and signal traces routed, need to connect outstanding grounds and fix a few routing misconnects
    [analog-board.kicad_pcb, analog-board.sch]
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2015-03-14 stiching grounds, will need to move LFO SIP module
    [analog-board.kicad_pcb]
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2015-03-14 all routed, need to tweak and move LFO module
    [analog-board.kicad_pcb]
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2015-03-15 routing done, still some tweaking to do, 3D render is almost done
    [analog-board.kicad_pcb]
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2015-03-15 added more test points, including power input points
    [analog-board.kicad_pcb, analog-board.sch]
2015-03-15 a little more tweaking to be done. Need to consider ferrite beads on power supply
    [analog-board.kicad_pcb]
2015-03-17 more tweaking finished, not much left to do. fixed VCO outline orientation - the bulk of the mold was on the wrong side in the module footprint
    [analog-board.kicad_pcb]
2015-03-21 made a few changes to digital board for 3D rendering
    [digital-board.kicad_pcb]
2015-03-22 changes to analog board for better 3D representation, plus moved sample and hold noise source caps down to clear MIDI jack on digital board in final pcb assembly
    [analog-board.kicad_pcb]
2015-03-26 about half done silkscreen cleanup. Still need to add 1V/oct CV input on pitch summer
    [analog-board.kicad_pcb]
2015-03-26 adding external CV and GATE input test points
    [analog-board.sch]
2015-03-26 CV and GATE test points added and routed
    [analog-board.kicad_pcb]
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2015-03-30 fixed 7805 DPAK footprint, fixed DG212 pin swap. footprints checked, ready to order
    [analog-board.kicad_pcb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]
2015-03-30 ignoring analog-board in Gerbers folder for now, will add once PCB ordrerd. Just restored digital-board folder in Gerbers folder
    [digital-board-B_Cu.gbl, digital-board-B_Mask.gbs, digital-board-B_SilkS.gbo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]
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2015-03-31 enlarged pol cap holes, they were too small. about to order PCB
    [analog-board.kicad_pcb, analog-board.sch]
2015-05-21 last commit before changing PCB errors in revision 1.0. Discovered thus far: 7905 -ve power regulator pins are incorrect, so whole power section is useless in this version. LFO demultiplexer doesn't 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
2015-05-22 added 74HC75 LFO demux latch and fixed 7912 negative voltage regulator pin out. Not finished routing new changes
    [analog-board.kicad_pcb, analog-board.sch]
2015-05-24 74LC75 quad latch added and routed. Probably need to change layout of S&H circuit as there is droop
    [analog-board.kicad_pcb, analog-board.sch]
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2015-05-24 fixed Q6 swap in schematic and rerouted
    [analog-board.kicad_pcb, analog-board.sch]
2015-05-25 shuffled U13 and U14 group S&H/CV traces a bit to try to reduce coupling. Hardly enough room to do anything meaningful
    [analog-board.kicad_pcb]
2015-05-29 fixed R73 and R78 label swap on PCB silkscreen. Added notes to schematic about changing feedback resistor value to reduce gain of waveform and summing mixers
    [analog-board.kicad_pcb, analog-board.sch]
2015-06-21 added some notes to schematic about capacitor packages and values based on evalutation of v1.0 analog board
    [analog-board.sch]
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2015-06-22 add 220K resistors to PWM LFO modulation summer to balance LFO waveform around 0V
    [analog-board.kicad_pcb]
2015-06-22 added resistor dividers for pulse output on VCOs and LFO to get 10Vpp pulse level
    [analog-board.kicad_pcb, analog-board.sch]
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2015-07-07 moved final DC blocking cap to output of volume VCA, deleted ring output resistor to J2
    [analog-board.kicad_pcb, analog-board.sch]
2015-07-30 added note about changing R11 and R117 to 470K for VCO1 and FIL cutoff modulation by EG2
    [analog-board.sch]
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2015-08-05 moved U36 and U46 from bottom side of board to top side, routed, adjusted routing and labels. Q36 footprint triple checked now
    [analog-board.kicad_pcb]
2015-08-06 basically done. need to do last quick check of a few footprints, but otherwise board is ready to order. Will place order upon returning from Lighthouse
    [analog-board.kicad_pcb, analog-board.sch]
2015-08-11 few touch ups and silkscreen corrections. Ready to order from Seeed Studio
    [analog-board.kicad_pcb, analog-board.sch]
2015-09-12 just added a few notes about removing filter pitch depth control VCA and maybe repurposing OTA for Mike Simms dual OTA VCA for final volume VCA
    [$analog-board.sch]
2015-09-18 couple of notes added - power supply is WRONG and needs to be revised. Thermal vias for L7912 and L7812 need to be added and U36 package needs to be adjusted
    [$analog-board.sch, analog-board.kicad_pcb, analog-board.sch]
2015-09-22 few changes to schematic not implemented in board yet to refelct hacks to analog board v1.1
    [analog-board.sch]
2015-09-24 tiny changes to silkscreen and hidden value positions to make pcb file easier reference for building
    [analog-board.kicad_pcb]
